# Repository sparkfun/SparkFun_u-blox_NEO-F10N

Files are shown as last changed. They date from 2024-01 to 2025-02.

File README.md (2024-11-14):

SparkFun GNSS L1/L5 Breakout- NEO-F10N, SMA
========================================

SparkFun GNSS L1/L5 Breakout - NEO-F10N, SMA (https://www.sparkfun.com/products/24114)

[*SparkFun GNSS L1/L5 Breakout - NEO-F10N, SMA (GPS-24114)*](https://www.sparkfun.com/products/24114)

The SparkFun GNSS L1/L5 Breakout - NEO-F10N, SMA is a standard precision GNSS board with meter-level positional accuracy. The NEO-F10N uses the L1/L5 bands instead of the more commonly seen L1/L2 bands. Utilizing the L5 band, the NEO-F10N delivers improved performance under challenging urban environments. The L5 signals fall within the protected ARNS (aeronautical radio navigation service) frequency band, leading to less RF interference.

This breakout supports the concurrent reception of three GNSS constellations: GPS, Galileo, and BeiDou. The proprietary dual-band multipath mitigation technology from the u-blox F10 allows the module to choose the best signals from both bands to achieve a significantly better position accuracy in challenging urban environments than with the L1 band alone.

What's different from other u-blox modules is that the NEO-F10N module only supports one serial UART communication port. We included a CH340 USB-to-serial converter to connect the board to a computer's USB port easily. For users connecting the board's serial UART pins to a microcontroller or radio, you will need to cut the USB-TX and USB-RX jumpers to avoid bus contention. Pins for power, serial, pulse per second, and control pins are broken out to 0.1"-spaced pins on the board's edge. We have also conveniently included a 1x6 header should you connect a BlueSMiRF v2 to transmit data wirelessly!

The breakout is also has an on-board rechargeable battery that provides power to the RTC on the NEO-F10N. This reduces the time-to-first fix from a cold start (~28s) to a hot start (2s). The battery will maintain RTC and GNSS orbit data without being connected to power for plenty of time. We have included an SMA connector for a secure connection.

U-blox-based GPS products are configurable using the popular but dense Windows program u-center. Plenty of different functions can be configured on the NEO-F10N: baud rates, update rates, spoofing detection, external interrupts, SBAS, etc. To get started, we've included a few basic UART examples with our SparkFun Arduino Library.

Repository Contents
-------------------
* **.github/workflows** - YAML files used for GitHub Actions and GitHub Pages/mkdocs
* **/Hardware** - KiCad design files (.brd, .sch)
  * **/Production** - Production panel files (.brd)
* **/docs** - Online documentation files
  * **/assets** - Folder containing all the file assets used for product documentation
    * **/3d_model** - Exported 3D models from KiCad
    * **/board_files** - Copy of design files used for product documentation
    * **/component_documentation** - Datasheets and manuals for hardware components
    * **/img** - Images for product documentation
  * **/github** - Files stating how to contribute and filing issues used for product documentation
  * **/javascript** - Folder containing custom javascript used for product documentation
  * **/stylesheet** - Folder containing CSS files used for product documentation
* **/overrides** - Customization files used for product documentation
  * **/.icons** - Icons used for GitHub used for product documentation
  * **./partials** - Used for product documentation

Documentation
--------------
* **[Library](https://github.com/sparkfun/SparkFun_u-blox_GNSS_v3)** - Arduino library for u-blox modules.
* **[Hookup Guide](https://docs.sparkfun.com/SparkFun_u-blox_NEO-F10N)** - Basic hookup guide for the NEO-F10N breakout board.

Product Versions
----------------
* [GPS-24114](https://www.sparkfun.com/products/24114) - Initial release

Version History
---------------
* v1.0 - Initial release

License Information
-------------------

This product is _**open source**_!

Please review the LICENSE.md file for license information.

If you have any questions or concerns on licensing, please contact technical support on our [SparkFun forums](https://forum.sparkfun.com/viewforum.php?f=152).

Distributed as-is; no warranty is given.

- Your friends at SparkFun.

_<COLLABORATION CREDIT>_

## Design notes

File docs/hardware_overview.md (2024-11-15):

In this section, we will highlight the hardware and pins that are broken out on the SparkFun GNSS L1/L5 Breakout - NEO-F10N, SMA. For more information, check out our [Resources and Going Further](../resources/) for the NEO-F10N.

<div style="text-align: center;">
  <table>
    <tr style="vertical-align:middle;">
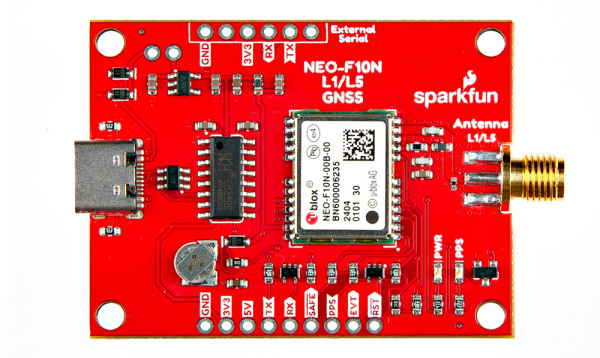
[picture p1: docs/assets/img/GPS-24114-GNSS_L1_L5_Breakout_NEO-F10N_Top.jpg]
     <td style="text-align: center; vertical-align: middle; border: solid 1px #cccccc;></td>
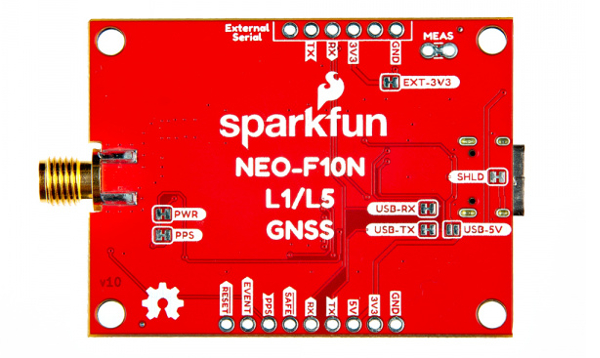
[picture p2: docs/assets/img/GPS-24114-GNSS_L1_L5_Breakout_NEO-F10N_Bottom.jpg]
Bottom View
     <td style="text-align: center; vertical-align: middle; border: solid 1px #cccccc;></td>
    </tr>
    <tr style="vertical-align:middle;">
     <td style="text-align: center; vertical-align: middle; border: solid 1px #cccccc;"><i>Top View</i></td>
     <td style="text-align: center; vertical-align: middle; border: solid 1px #cccccc;"><i>Bottom View</i></td>
    </tr>
  </table>
</div>

### NEO-F10N Module

The board breaks out the NEO-F10N with some application circuits.

<div style="text-align: center;">
  <table>
    <tr style="vertical-align:middle;">
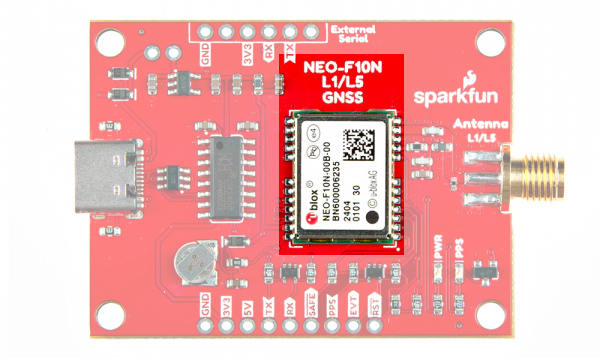
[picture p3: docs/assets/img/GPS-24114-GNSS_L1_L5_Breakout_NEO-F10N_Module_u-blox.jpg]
u-blox NEO-F10N Module
     <td style="text-align: center; vertical-align: middle; border: solid 1px #cccccc;></td>
    </tr>
    <tr style="vertical-align:middle;">
     <td style="text-align: center; vertical-align: middle; border: solid 1px #cccccc;"><i>u-blox NEO-F10N Module</i></td>
    </tr>
  </table>
</div>

Similar to the other u-blox engines, the NEO-F10N is a GNSS Receiver. The module supports the concurrent reception of three GNSS systems: GPS, Galileo, and BeiDou. The NEO-F10N utilizes the L1/L5 bands as opposed to other u-blox modules that use L1/L2, such as the [NEO-M9N](https://www.sparkfun.com/products/17285).

<div style="text-align: center;">
  <table>
    <tr style="vertical-align:middle;">
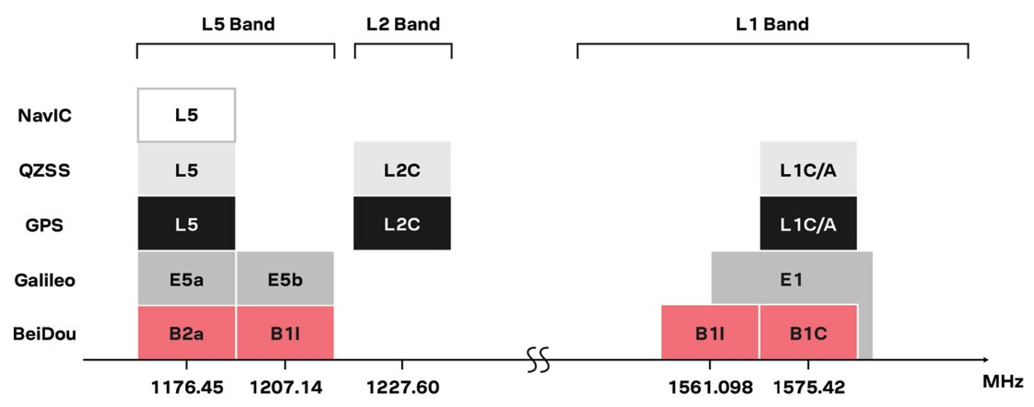
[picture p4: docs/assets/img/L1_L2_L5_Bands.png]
L1, L2, L5 GNSS Frequency Bands
     <td style="text-align: center; vertical-align: middle; border: solid 1px #cccccc;></td>
    </tr>
    <tr style="vertical-align:middle;">
     <td style="text-align: center; vertical-align: middle; border: solid 1px #cccccc;"">Image Courtesy of <a href="../assets/component_documentation/GPS-signals-migration-wp.pdf">u-blox: GPS Signals Migration White Paper</a></td>
    </tr>
  </table>
</div>

Utilizing the L5 band, the NEO-F10N delivers improved performance under challenging urban environments because the L5 signals fall within the protected ARNS (aeronautical radio navigation service) frequency band. This band is less subject to RF interference. Below is a comparison of a single-band (L1) vs dual-band (L1/L5) GNSS test with a car driving through an urban environment. Tracking the vehicle was better when utilizing the L1/L5 bands.

<div style="text-align: center;">
  <table>
    <tr style="vertical-align:middle;">
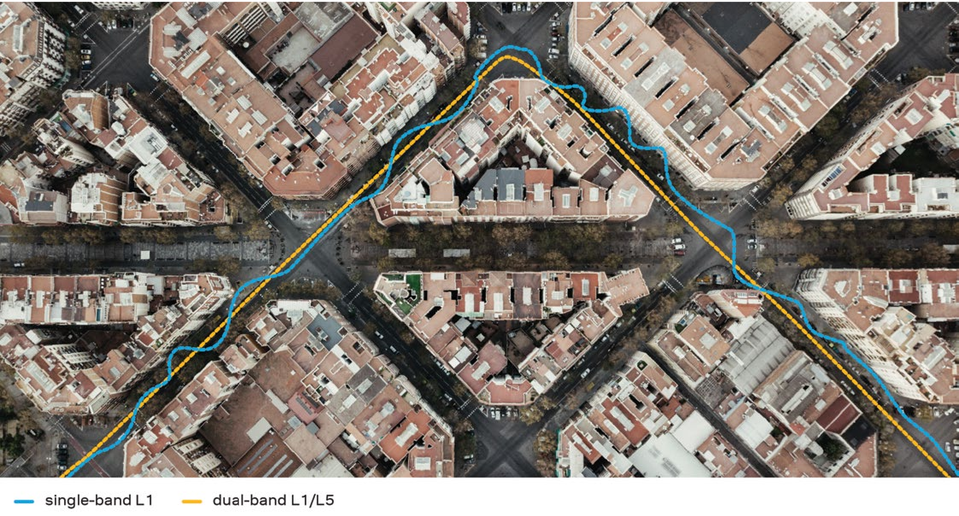
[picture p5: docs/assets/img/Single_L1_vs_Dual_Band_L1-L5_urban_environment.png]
     <td style="text-align: center; vertical-align: middle; border: solid 1px #cccccc;></td>
    </tr>
    <tr style="vertical-align:middle;">
     <td style="text-align: center; vertical-align: middle; border: solid 1px #cccccc;"><i>Image Courtesy of <a href="../assets/component_documentation/GPS-signals-migration-wp.pdf">u-blox: GPS Signals Migration White Paper</a></i></td>
    </tr>
  </table>
</div>

!!! note
    As of the writing of this tutorial, it is important to note that L5 band is still not yet fully operational on GPS and Galileo. It is expected to be fully operational by 2025.

The module can achieve meter-level accuracy with a satellite lock. Below are a few specs taken from the datasheet. For more information, check out the related [documents for the NEO-F10N in the Resources](../resources/).

* Time to First Fix: 28s (cold), 2s (hot)
* Max Navigation Rate for Single GNSS Configuration (GPS): 20 Hz
* Positional Accuracy (GPS): 1.5m
* Time Pulse Accuracy: 30ns
* Operational Limits
    * Max G: &le; 4G
    * Max Altitude: 80km (49.7 miles)
    * Max Velocity: 500m/s (1118mph)
* Software Configurable
    * Baud Rate (**38400 Baud**, default)
    * Odometer
    * Spoof Detection
    * External Interrupt
    * Pin Control
    * Many others!
* Supports: NMEA, UBX over UART

### Power

There are a variety of power and power-related nets broken out on the USB connector and through hole pads. **5V** power from the USB C Connector or PTH is regulated down to **3.3V** with the AP2112K 3.3V/600mA voltage regulator. The logic levels for the NEO-F10N is **3.3V** for the I/O pins.

* **5V** &mdash; Power from the USB C connector's VBUS provides power to the 5V bus. The 5V net is also connected to the edge PTH pin labeled as **5V** and the input of the 3.3V voltage regulator. Built-in Schottky diodes are included on the VBUS and 5V nets for protection. Make sure that power you provide to this pin does not exceed 6 volts.
* **3V3** &mdash; This connects to the 3.3V net. Both sides of the board includes a 3.3V pin (labeled as 3V3) that should only be provided with a clean 3.3V power signal.
* **GND** &mdash; Of course, is the common, ground voltage (0V reference) for the system.

<div style="text-align: center;">
  <table>
    <tr style="vertical-align:middle;">
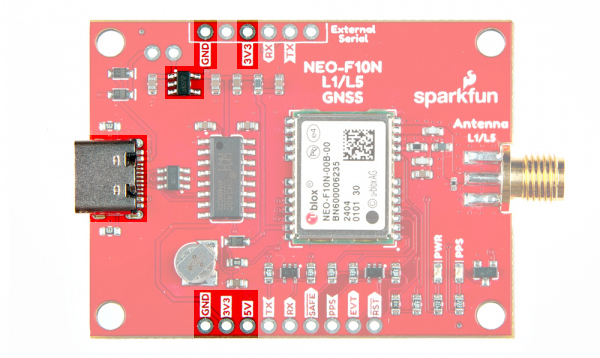
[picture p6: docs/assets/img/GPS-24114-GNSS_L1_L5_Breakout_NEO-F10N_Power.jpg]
Power Nets Highlighted
     <td style="text-align: center; vertical-align: middle; border: solid 1px #cccccc;"></td>
    </tr>
    <tr style="vertical-align:middle;">
     <td style="text-align: center; vertical-align: middle; border: solid 1px #cccccc;"><i>Power from USB and PTHs</i></td>
    </tr>
  </table>
</div>

### Backup Battery

The small metal disk is a small lithium battery. This battery does not provide power to the IC like the 3.3V system does, but to relevant systems inside the IC that allow for a quick reconnection to satellites. The first time to fix (TTFF) is about **~28 seconds**. With the backup battery, the hot start is less than **2 seconds**.

<div style="text-align: center;">
  <table>
    <tr style="vertical-align:middle;">
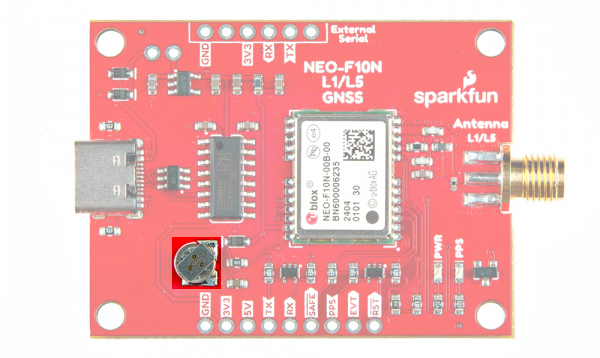
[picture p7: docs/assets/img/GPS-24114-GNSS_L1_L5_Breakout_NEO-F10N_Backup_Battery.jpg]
Backup Battery Highlighted
     <td style="text-align: center; vertical-align: middle; border: solid 1px #cccccc;"></td>
    </tr>
    <tr style="vertical-align:middle;">
     <td style="text-align: center; vertical-align: middle; border: solid 1px #cccccc;"><i>Backup Battery Highlighted</i></td>
    </tr>
  </table>
</div>

### CH340C USB-to-Serial Converter

The board includes a built-in CH340 USB-to-serial converter to connect the board to a computer's USB port. This is useful for users viewing data, configuring the NEO-F10N, or updating firmware through u-center graphical user interface (GUI). Of course, users can also view the serial data through a serial terminal as well.

<div style="text-align: center;">
  <table>
    <tr style="vertical-align:middle;">
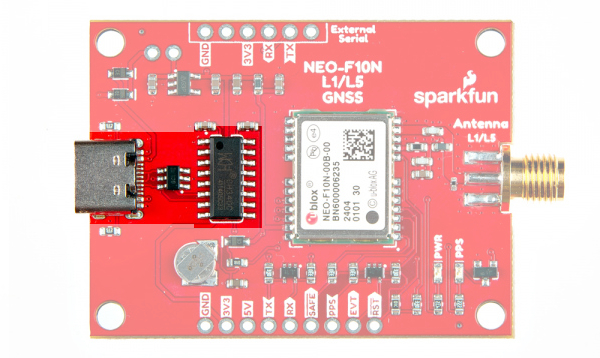
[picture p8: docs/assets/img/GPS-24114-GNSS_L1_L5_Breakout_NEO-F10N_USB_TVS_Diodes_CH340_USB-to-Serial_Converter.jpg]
CH340C Highlighted
     <td style="text-align: center; vertical-align: middle; border: solid 1px #cccccc;"></td>
    </tr>
    <tr style="vertical-align:middle;">
     <td style="text-align: center; vertical-align: middle; border: solid 1px #cccccc;"><i>USB, TVS Diodes, and CH340 Highlighted</i></td>
    </tr>
  </table>
</div>

### UART1

There are two pins on each row of headers currently labeled as **TX** and **RX** for the UART. Compared to other u-blox modules, there is no USB, I<sup>2</sup>C, SPI, or secondary UART port. The NEO-F10N has only one serial UART port available. The default baud rate is set to **38400 baud**, 8-bits, no parity, and 1 stop bit. The NEO-F10N is set to output the following messages by default: NMEA GGA, GLL, GSA, GSV, RMC, VTG and TXT.

* **TX** &mdash; TX out from the NEO-F10N
* **RX** &mdash; RX into the NEO-F10N

<div style="text-align: center;">
  <table>
    <tr style="vertical-align:middle;">
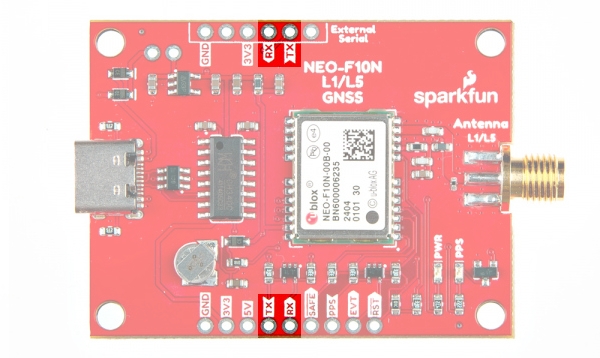
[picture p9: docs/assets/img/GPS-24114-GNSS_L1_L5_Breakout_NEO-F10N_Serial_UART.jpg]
UART1 Highlighted
     <td style="text-align: center; vertical-align: middle; border: solid 1px #cccccc;"></td>
    </tr>
    <tr style="vertical-align:middle;">
     <td style="text-align: center; vertical-align: middle; border: solid 1px #cccccc;"><i>UART Pins Highlighted</i></td>
    </tr>
  </table>
</div>

These pins are currently tied to the CH340's UART pins. For users connecting the board's serial UART pins to a microcontroller or radio, you will need to cut the USB-TX and USB-RX jumpers to avoid [bus contention](https://learn.sparkfun.com/tutorials/serial-communication/common-pitfalls).  

The 1x6 header labeled as "External Serial" can be used to connect to any other serial device that has a standard serial UART header. For example, you can connect a BlueSMiRF v2 wirelessly stream serial data using SPP to a smartphone's Bluetooth&reg; or a second BlueSMiRF.

<div style="text-align: center;">
  <table>
    <tr style="vertical-align:middle;">
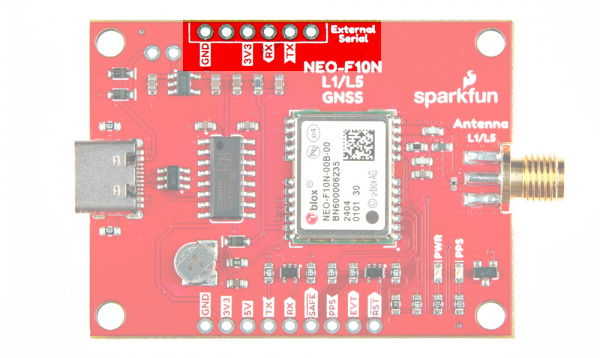
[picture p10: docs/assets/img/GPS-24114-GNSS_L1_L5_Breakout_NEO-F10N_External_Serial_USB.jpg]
External Serial Highlighted
     <td style="text-align: center; vertical-align: middle; border: solid 1px #cccccc;"></td>
    </tr>
    <tr style="vertical-align:middle;">
     <td style="text-align: center; vertical-align: middle; border: solid 1px #cccccc;"><i>External Serial Highlighted</i></td>
    </tr>
  </table>
</div>

### SMA Connector

The board is populated with one SMA connector for a secure connection. You will need a multiband GNSS antenna capable of receiving L1 and L5 bands to get the most out of the NEO-F10N. Note that this is intended for active antennas. We recommend using the
[GNSS L1/L5 Multi-Band High Precision Antenna - 5m (SMA)](https://www.sparkfun.com/products/23814). You will also need an [antenna ground plate](https://www.sparkfun.com/products/17519)

<div style="text-align: center;">
  <table>
    <tr style="vertical-align:middle;">
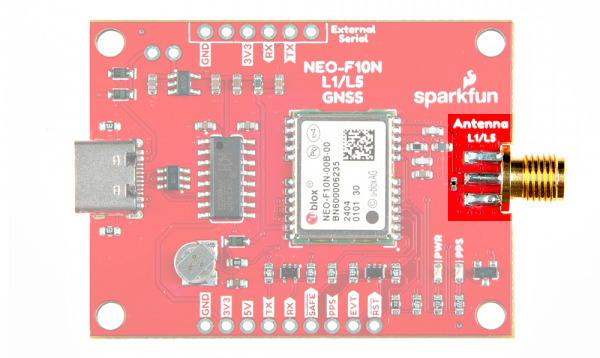
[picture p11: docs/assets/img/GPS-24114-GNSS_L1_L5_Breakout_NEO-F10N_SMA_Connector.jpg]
SMA Connector Highlighted
     <td style="text-align: center; vertical-align: middle; border: solid 1px #cccccc;"></td>
    </tr>
    <tr style="vertical-align:middle;">
     <td style="text-align: center; vertical-align: middle; border: solid 1px #cccccc;"><i>SMA Connector Highlighted</i></td>
    </tr>
  </table>
</div>

### Broken Out Pins

There are four other pins broken out:

* **<span STYLE="text-decoration:overline">SAFE</span>** &mdash; Safeboot input pin. This is required for firmware updates to the module and generally should not be used or connected.
* **PPS** &mdash; Pulse-per-second output pin. Begins blinking at 1Hz when module gets basic GPS/GNSS position lock.
* **EVENT** &mdash; Interrupt input/output pin. Can be configured using U-Center to bring the module out of deep sleep or to output an interrupt for various module states.
* **<span STYLE="text-decoration:overline">RST</span>**/ **<span STYLE="text-decoration:overline">RESET</span>** &mdash; Reset input pin. Pull this line low to reset the module.

<div style="text-align: center;">
  <table>
    <tr style="vertical-align:middle;">
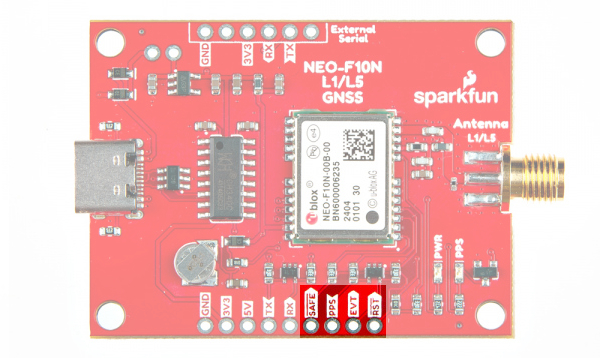
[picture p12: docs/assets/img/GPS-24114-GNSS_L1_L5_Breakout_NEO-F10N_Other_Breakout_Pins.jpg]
     <td style="text-align: center; vertical-align: middle; border: solid 1px #cccccc;"></td>
    </tr>
    <tr style="vertical-align:middle;">
     <td style="text-align: center; vertical-align: middle; border: solid 1px #cccccc;"><i>Other Breakout Pins Highlighted</i></td>
    </tr>
  </table>
</div>

### LEDs

The board includes the following status LEDs as indicated in the image below.

* **PWR** &mdash; Indicates when the NEO-F10N is powered.
* **PPS** &mdash; Tied to the Pulse Per Second pin and acts as a visual indicator to the NEO-F10N's pulse per second signal.

<div style="text-align: center;">
  <table>
    <tr style="vertical-align:middle;">
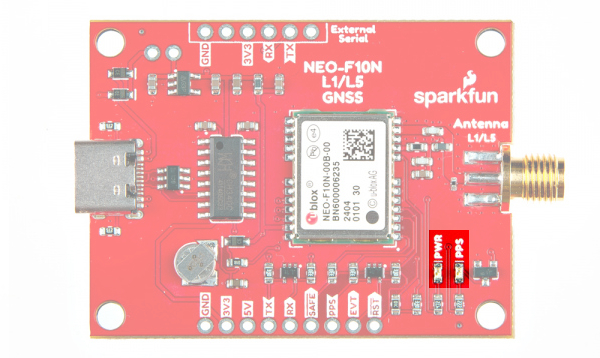
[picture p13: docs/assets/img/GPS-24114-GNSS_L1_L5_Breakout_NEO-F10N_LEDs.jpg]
LEDs Highlighted
     <td style="text-align: center; vertical-align: middle; border: solid 1px #cccccc;"></td>
    </tr>
    <tr style="vertical-align:middle;">
     <td style="text-align: center; vertical-align: middle; border: solid 1px #cccccc;"><i>LEDs Highlighted</i></td>
    </tr>
  </table>
</div>

### Jumpers

!!!note
    If this is your first time working with jumpers, check out the [How to Work with Jumper Pads and PCB Traces](https://learn.sparkfun.com/tutorials/how-to-work-with-jumper-pads-and-pcb-traces/all) tutorial for more information.

If you flip the board over, you will notice a few jumper pads.

* **SHLD** &mdash; This jumper connects the USB Type C connector's shield pin to GND. By default, this is closed. Cut this to isolate the USB Type C connector's shield pin.
* **USB-5V** &mdash; This jumper connects the 5V net to the 5V VBUS net. By default, this is open. Add a solder blob to the jumper to connect 5V PTH to the USB's VBUS.
* **MEAS** &mdash; By default, the jumper is closed. You can cut this jumper and solder to the PTHs to measure the NEO-F10N's current draw from either the USB's VBUS or 5V net. Just make sure to close the jumper if you decide to still use power from the USB or the 5V pin.
* **USB-TX** &mdash; The USB-TX jumper connects the CH340 USB-to-Serial converter's RX pin to the  NEO-F10N's TX pin. As stated earlier, cut this trace when connecting another serial device on the PTH to avoid bus contention.
* **USB-RX** &mdash; The USB-RX jumper connects the CH340 USB-to-Serial converter's TX pin to the  NEO-F10N's RX pin. As stated earlier, cut this trace when connecting another serial device on the PTH to avoid bus contention.
* **EXT-3V3** &mdash; This jumper connects 3.3V to the external serial port. By default, this is closed and will provide power to anything connected to the external serial port. To avoid conflicting voltages, cut this jumper if you are connecting 3.3V USB device with its own power source to the 1x6 header while the GNSS receiver is being powered with its own power source.
* **PWR** &mdash; The power LED will illuminate when 3.3V is activated either over USB or via the 3v3 pin. Cut this jumper to disable the LED.
* **PPS** &mdash; The pulse per second LED will illuminate each second once a position lock has been achieved. Cut this jumper to disable the LED.

<div style="text-align: center;">
  <table>
    <tr style="vertical-align:middle;">
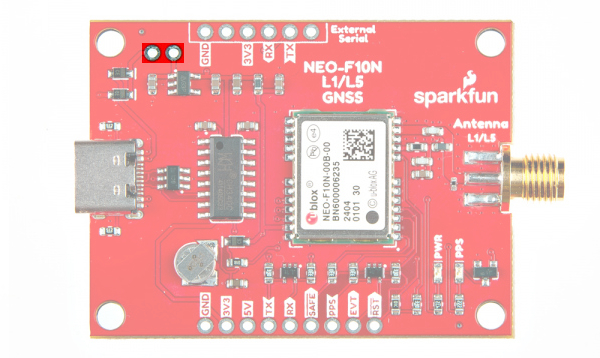
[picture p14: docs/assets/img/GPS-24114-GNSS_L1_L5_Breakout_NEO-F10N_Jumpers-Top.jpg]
Jumpers Highlighted
     <td style="text-align: center; vertical-align: middle; border: solid 1px #cccccc;"></td>
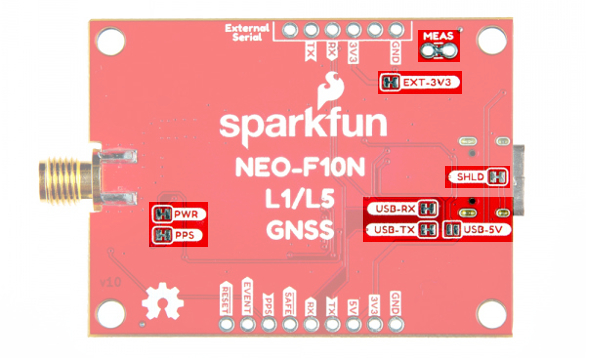
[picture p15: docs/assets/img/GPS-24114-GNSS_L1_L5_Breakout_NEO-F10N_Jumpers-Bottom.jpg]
Jumpers Highlighted
     <td style="text-align: center; vertical-align: middle; border: solid 1px #cccccc;"></td>
    </tr>
    <tr style="vertical-align:middle;">
     <td style="text-align: center; vertical-align: middle; border: solid 1px #cccccc;"><i>MEAS PTH Highlighted - Top View</i></td>
     <td style="text-align: center; vertical-align: middle; border: solid 1px #cccccc;"><i>Jumpers Highlighted Highlighted - Bottom View</i></td>
    </tr>
  </table>
</div>

### 3D Model

3D models of the board and components were exported to STEP and STL files using KiCad.

<!-- Import the component -->
<script type="module" src="https://ajax.googleapis.com/ajax/libs/model-viewer/3.5.0/model-viewer.min.js"></script>

<div style="text-align: center;">
    <model-viewer src="../assets/3d_model/SparkFun_NEO-F10N_3D_model.glb" camera-controls poster="../assets/3d_model/SparkFun_NEO-F10N_3D_image.png" environment-image="legacy" shadow-intensity="1.58" exposure="0.64" shadow-softness="0.24" tone-mapping="neutral" camera-orbit="-46.67deg 57.14deg 153.3m" field-of-view="30deg" style="width: 750px; height: 500px;">
    </model-viewer>
</div>
<br />
<div style="text-align: center">
    <a href="../assets/3d_model/SparkFun_NEO-F10N_3D_model.step" target="stp_file" class="md-button">Click Here for the STEP File</a>
</div>

### Board Dimensions

The board is 50.8mm x 38.1mm (2.0" x 1.5). This is not including the SMA connector. There are 4x mounting holes by each corner of the board for 4-40 screws and standoffs.

<div style="text-align: center;">
  <table>
    <tr style="vertical-align:middle;">
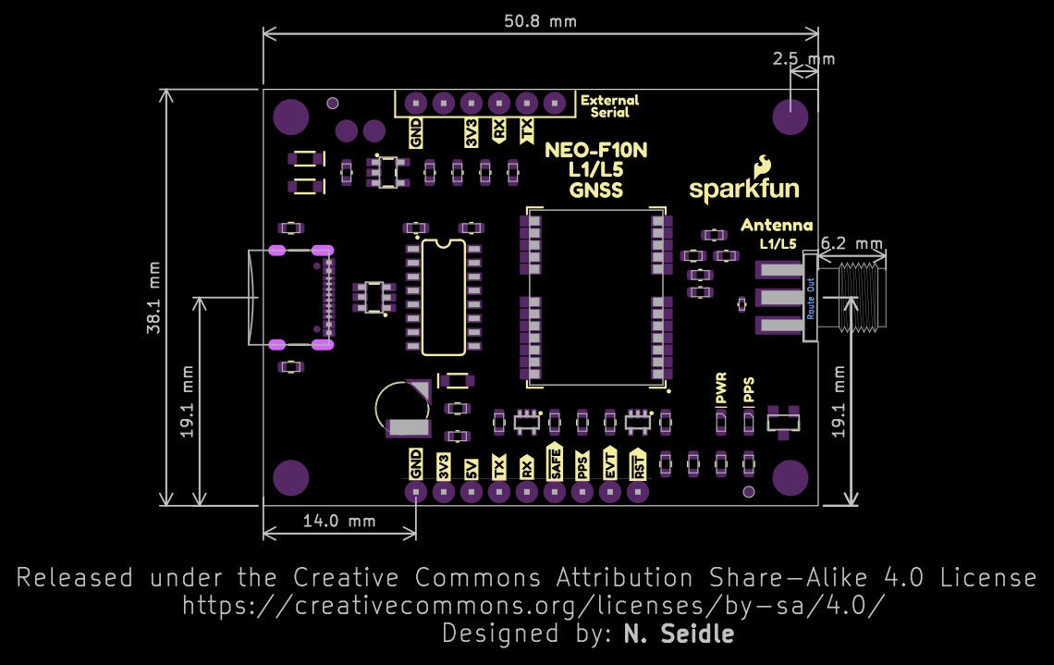
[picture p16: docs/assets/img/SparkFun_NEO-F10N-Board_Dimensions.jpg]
Board Dimensions
     <td style="text-align: center; vertical-align: middle; border: solid 1px #cccccc;"></td>
    </tr>
    <tr style="vertical-align:middle;">
     <td style="text-align: center; vertical-align: middle; border: solid 1px #cccccc;"><i>Board Dimensions</i></td>
    </tr>
  </table>
</div>

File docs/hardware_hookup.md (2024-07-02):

In this section, we'll go over how to connect the L1/L5 GNSS Antenna to the SparkFun GNSS L1/L5 Breakout - NEO-F10N. Depending on your application, you can connect the SparkFun GNSS L1/L5 Breakout - NEO-F10N directly to your computer.  For embedded application, you will want to connect the SparkFun GNSS L1/L5 Breakout - NEO-F10N to the IoT RedBoard - ESP32.

### L1/L5 Dual-Band GNSS Antenna

Connect a compatible dual-band antenna that is capable of receiving L1 and L5 bands. In this case, we used the "GNSS L1/L5 Multi-Band High Precision Antenna - 5m (SMA)." Insert the SMA side of the interface cable into the GNSS L1/L5 Breakout Board's SMA connector. Secure the connection by using the SMA's hex nut until it is finger-tight.

<div style="text-align: center;">
  <table>
    <tr style="vertical-align:middle;">
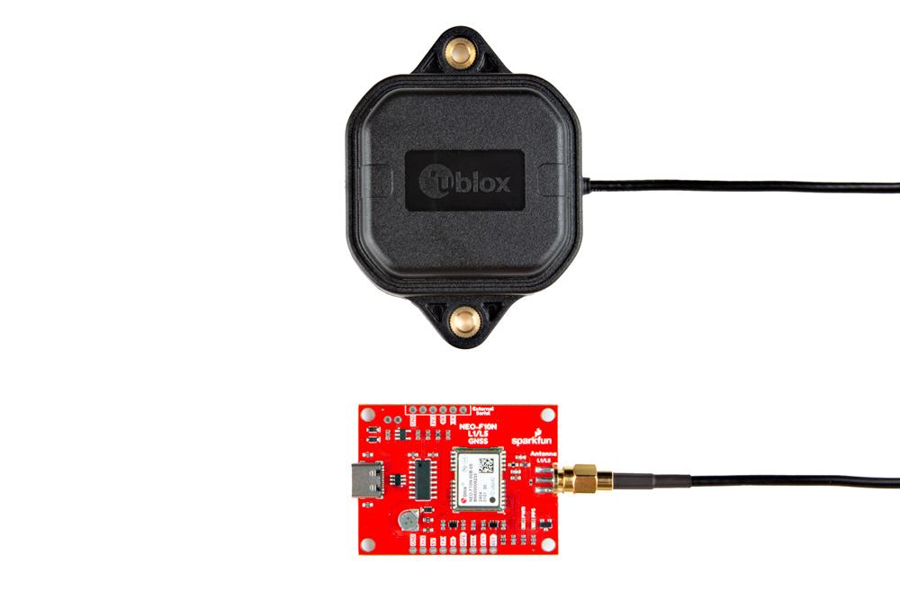
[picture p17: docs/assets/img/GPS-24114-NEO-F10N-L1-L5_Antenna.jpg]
Antenna Connected to Breakout Board
     <td style="text-align: center; vertical-align: middle;"></td>
    </tr>
  </table>
</div>

You will need to include an [antenna ground plate](https://www.sparkfun.com/products/17519) to get the most of the multi-band antenna. For the following images below, we'll have the magnetic mount antenna separate from the antenna ground plate when connecting the NEO-F10N breakout board to the rest of the system. When running the examples, make sure to have the antenna mounted over a metal ground plate.

<div style="text-align: center;">
  <table>
    <tr style="vertical-align:middle;">
     <td style="text-align: center; vertical-align: middle;"><a href="https://cdn.sparkfun.com//assets/parts/1/6/5/9/3/17519-GPS_Antenna_Ground_Plate-05.jpg">GNSS Antenna Magnetically Mounted on Metal Antenna Ground Plate</a></td>
    </tr>
  </table>
</div>

!!! note
    Not all multiband antennas are made the same! Make sure that you are connecting a multi-band antenna that is capable of receiving L1/L5 signals when using the SparkFun GNSS L1/L5 Breakout - NEO-F10N. There is also another u-blox antenna that looks the same. However, the u-blox antenna used in this tutorial receives L1/L5 signals as opposed to the L1/L2.

### USB to NEO-F10N

For users that simply want to connect to the board via USB, you will just need to insert a USB C cable into the USB connector. Then connect the other end to your computer's USB port.

<div style="text-align: center;">
  <table>
    <tr style="vertical-align:middle;">
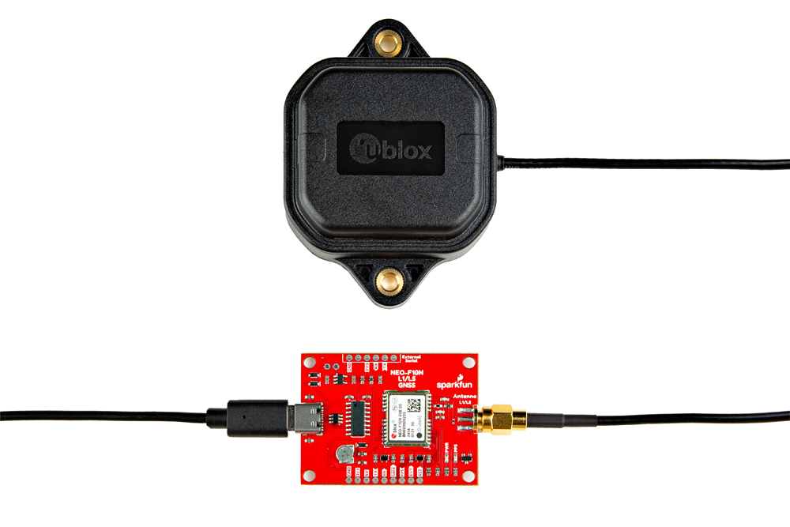
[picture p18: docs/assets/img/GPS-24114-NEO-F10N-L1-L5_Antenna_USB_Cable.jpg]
USB Cable Inserted into NEO-F10N
     <td style="text-align: center; vertical-align: middle;"></td>
    </tr>
  </table>
</div>

### Connecting via UART Port

!!! note
    We recommend using the IoT RedBoard - ESP32 for the scope of this tutorial.

For users that are connecting to a microcontroller, you will need to adjust the jumpers and solder to the PTH before connecting to the SparkFun GNSS L1/L5 Breakout - NEO-F10N.

#### Cutting the Serial Jumpers

For this example, we will connect the NEO-F10N to the IoT RedBoard - ESP32. Remember, the NEO-F10N has only one UART. You will need to cut the two jumpers on the back of the board labeled as USB-RX and USB-TX so that there is no [bus contention](https://learn.sparkfun.com/tutorials/serial-communication/common-pitfalls).

<div style="text-align: center;">
  <table>
    <tr style="vertical-align:middle;">
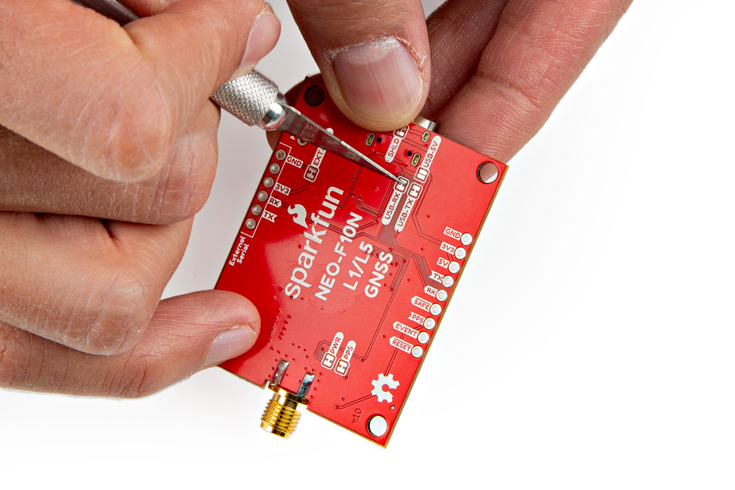
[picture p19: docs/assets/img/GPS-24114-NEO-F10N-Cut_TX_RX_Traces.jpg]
Cut Jumpers
     <td style="text-align: center; vertical-align: middle;"></td>
    </tr>
  </table>
</div>

#### Connecting via PTH

Once the jumpers have been cut, you will need to solder to the through hole pins. For temporary connections to the PTHs, you could use IC hooks to test out the pins. However, you'll need to solder headers or wires of your choice to the board for a secure connection. You can choose between a combination of [header pins and jumper wires](https://learn.sparkfun.com/tutorials/how-to-solder-through-hole-soldering/all), or [stripping wire and soldering the wire](https://learn.sparkfun.com/tutorials/working-with-wire/all) directly to the board.

<div class="grid cards col-4" markdown>

-   <a href="https://learn.sparkfun.com/tutorials/how-to-solder-through-hole-soldering/all">
      <figure markdown>
        How to Solder: Through Hole Soldering
      </figure>
    </a>

    ---

    <a href="https://learn.sparkfun.com/tutorials/how-to-solder-through-hole-soldering/all">
      <b>How to Solder: Through Hole Soldering</b>
    </a>
<!-- ----------WHITE SPACE BETWEEN GRID CARDS---------- -->

-   <a href="https://learn.sparkfun.com/tutorials/working-with-wire/all">
      <figure markdown>
        Working with Wire
      </figure>
    </a>

    ---

    <a href="https://learn.sparkfun.com/tutorials/working-with-wire/all">
      <b>Working with Wire</b>
    </a>
<!-- ----------WHITE SPACE BETWEEN GRID CARDS---------- -->
</div>

We decided to solder straight header pins to the 1x6 External Serial port. Your setup will look similar to the image below.

<div style="text-align: center;">
  <table>
    <tr style="vertical-align:middle;">
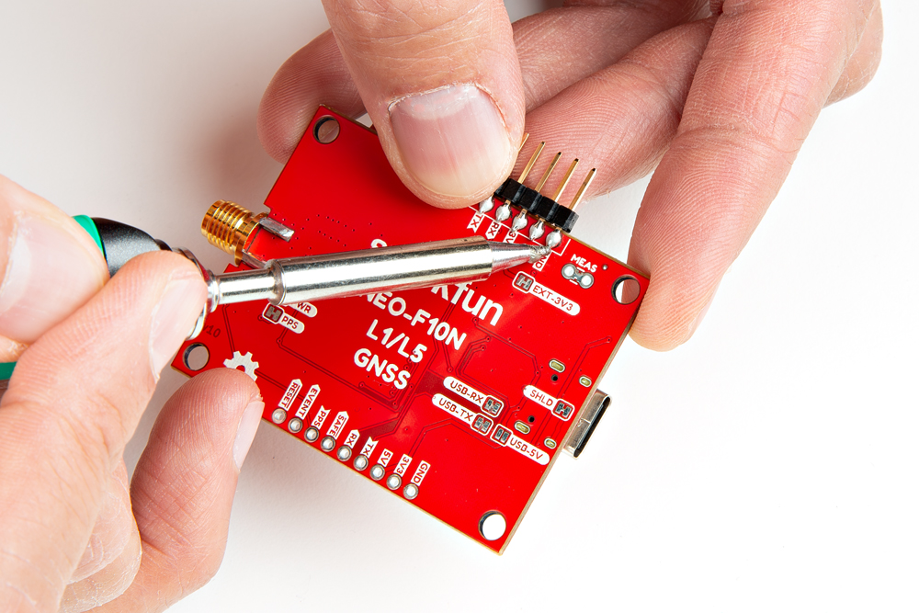
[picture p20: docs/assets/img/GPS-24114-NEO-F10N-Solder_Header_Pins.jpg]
Straight Header Pins connected to 1x6 Serial Port
     <td style="text-align: center; vertical-align: middle;"></td>
    </tr>
  </table>
</div>

You will then need to connect power and the UART pins between the boards. Below is an example of connecting the IoT RedBoard - ESP32's second hardware UART port. When initializing the serial, make sure to define your microcontroller's hardware serial, such as `Serial1` or `Serial2`. In this case, we needed to use UART2 for the IoT RedBoard - ESP32.

<div style="text-align: center;">
    <table>
        <tr>
            <th style="text-align: center; border: solid 1px #cccccc;">IoT RedBoard - ESP32
            </th>
            <th style="text-align: center; border: solid 1px #cccccc;">SparkFun GNSS L1/L5 Breakout - NEO-F10N
            </th>
        </tr>
        <tr>
            <td style="text-align: center; border: solid 1px #cccccc;" bgcolor="#f2dede"><font color="#000000">3.3V</font>
            </td>
            <td style="text-align: center; border: solid 1px #cccccc;" bgcolor="#f2dede"><font color="#000000">3V3</font>
            </td>
        </tr>
        <tr>        
            <td style="text-align: center; border: solid 1px #cccccc;" bgcolor="#fff3cd"><font color="#000000">UART2_TX (D17)</font>
            </td>
            <td style="text-align: center; border: solid 1px #cccccc;" bgcolor="#fff3cd"><font color="#000000">RX</font>
            </td>
        </tr>
        <tr>        
            <td style="text-align: center; border: solid 1px #cccccc;" bgcolor="#cce5ff"><font color="#000000">UART2_RX (D16)</font>
            </td>
            <td style="text-align: center; border: solid 1px #cccccc;" bgcolor="#cce5ff"><font color="#000000">TX</font>
            </td>
        </tr>
        <tr>
            <td style="text-align: center; border: solid 1px #cccccc;" bgcolor="#d4edda"><font color="#000000">GND</font>
            </td>
            <td style="text-align: center; border: solid 1px #cccccc;" bgcolor="#d4edda"><font color="#000000">GND</font>
            </td>
        </tr>
    </table>
</div>

<div style="text-align: center;">
  <table>
    <tr style="vertical-align:middle;">
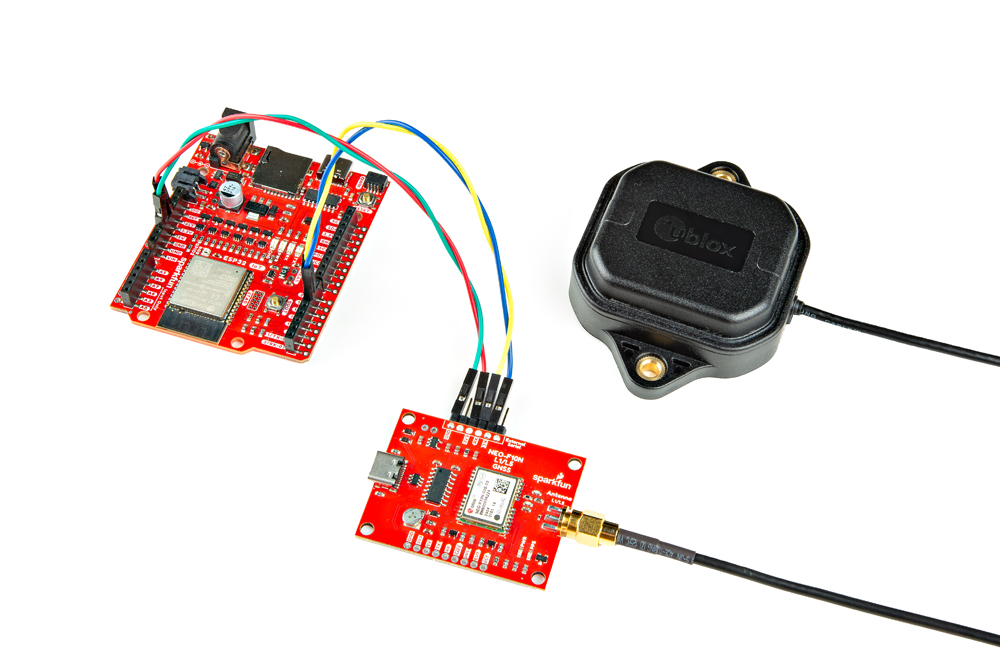
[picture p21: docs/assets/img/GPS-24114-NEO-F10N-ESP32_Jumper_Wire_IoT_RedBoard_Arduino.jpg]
NEO-F10N Breakout to Microcontroller with USB
     <td style="text-align: center; vertical-align: middle;"></td>
    </tr>
  </table>
</div>

!!! note
    Note that some microcontrollers may not have enough memory and will not be compatible with the SparkFun u-blox GNSS Arduino Library v3 (i.e. ATmega328P on the RedBoard Plus and the Arduino Uno). There are also some microcontrollers that only have one hardware UART so you need to make sure that there are only two serial devices on the bus.

#### USB to Microcontroller

To power and program the IoT RedBoard - ESP32, users will just need to insert the Type C side of the cable to the development board. The other end will connect to a computer's USB port.

<div style="text-align: center;">
  <table>
    <tr style="vertical-align:middle;">
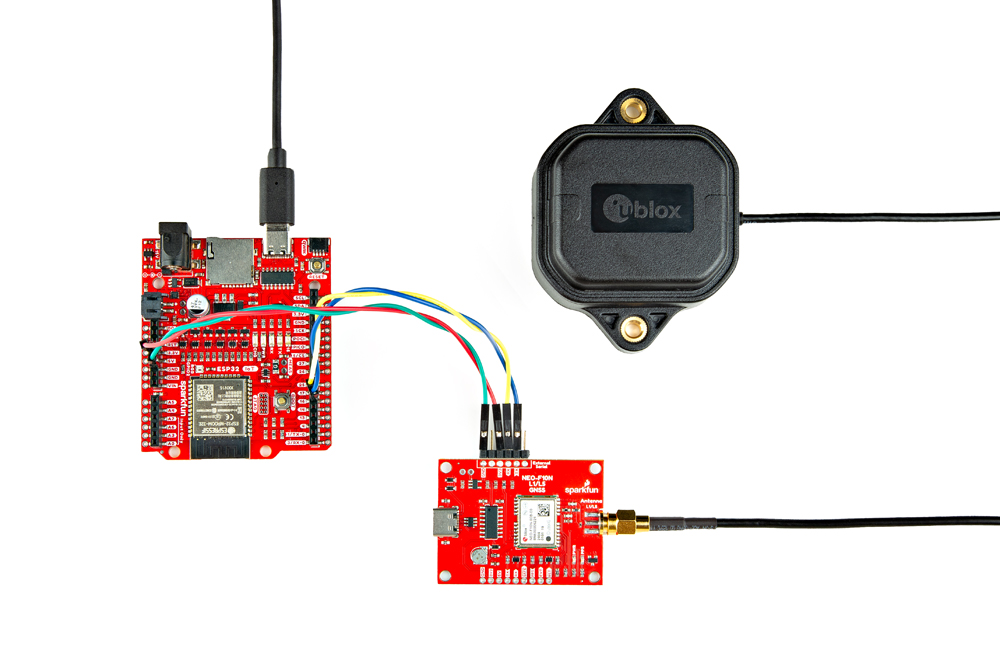
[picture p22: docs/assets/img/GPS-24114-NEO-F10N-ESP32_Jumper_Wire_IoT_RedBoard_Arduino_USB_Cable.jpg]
USB Cable Inserted into IoT RedBoard - ESP32 and NEO-F10N
     <td style="text-align: center; vertical-align: middle;"></td>
    </tr>
  </table>
</div>

#### Connecting a Pair of BlueSMiRF V2s

For users that want have a wireless connecting between the IoT RedBoard - ESP32 and the SparkFun GNSS L1/L5 Breakout Board - NEO-F10N, you could add a pair of BlueSMiRF V2s.

<div style="text-align: center;">
  <table>
    <tr style="vertical-align:middle;">
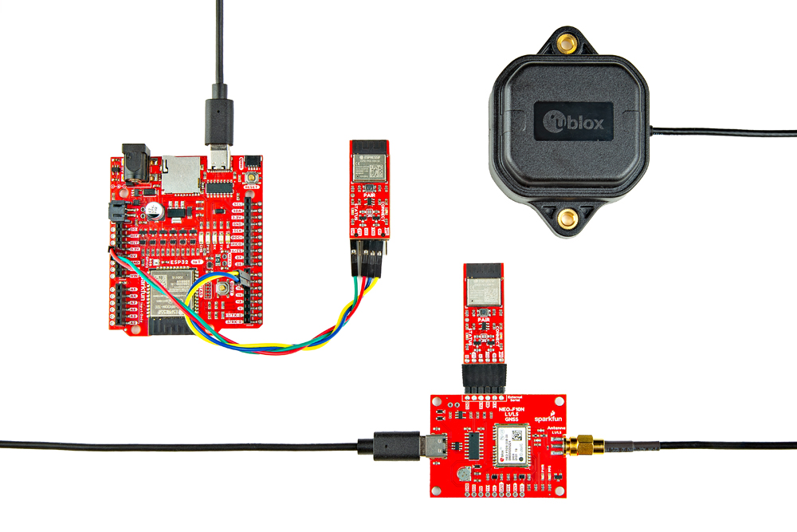
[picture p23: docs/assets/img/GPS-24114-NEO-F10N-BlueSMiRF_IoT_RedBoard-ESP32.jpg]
USB Cable Inserted into IoT RedBoard - ESP32/BlueSMiRF/Computer and USB Cable Inserted into BlueSMiRF/NEO-F10N
     <td style="text-align: center; vertical-align: middle;"></td>
    </tr>
  </table>
</div>

If you have not already, check out the [tutorial on the BlueSMiRFs](https://docs.sparkfun.com/SparkFun_BlueSMiRF-v2/introduction/) if you decide to wireless transmit the data.

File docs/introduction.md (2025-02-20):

The [SparkFun GNSS L1/L5 Breakout - NEO-F10N, SMA](https://www.sparkfun.com/products/24114) is a standard precision GNSS board with meter-level positional accuracy. The NEO-F10N uses the L1/L5 bands instead of the more commonly seen L1/L2 bands. Utilizing the L5 band, the NEO-F10N delivers improved performance under challenging urban environments the L5 signals fall within the protected ARNS (aeronautical radio navigation service) frequency band. This band is less subject to RF interference.

<center>
<div class="grid cards" style="width:500px;" markdown>

-   <a href="https://www.sparkfun.com/products/24114">
      <figure markdown>
        SparkFun GNSS L1/L5 Breakout - NEO-F10N, SMA
      </figure>
    </a>

    ---

    <a href="https://www.sparkfun.com/products/24114">
      <b>SparkFun GNSS L1/L5 Breakout - NEO-F10N, SMA</b>
      <br />
      GPS-24114
      <br />
      <center>[Purchase from SparkFun :fontawesome-solid-cart-plus:](https://www.sparkfun.com/products/24114){ .md-button .md-button--primary }</center>
    </a>
</div>
</center>

<div style="text-align: center;">
  <iframe width="560" height="315" src="https://www.youtube.com/embed/lrZWDXNU0OE?si=9YpjbiSuIA6uKVQY" title="YouTube video player" frameborder="0" allow="accelerometer; autoplay; clipboard-write; encrypted-media; gyroscope; picture-in-picture; web-share" referrerpolicy="strict-origin-when-cross-origin" allowfullscreen></iframe>
</div>

This breakout supports concurrent reception of three GNSS constellations: GPS, Galileo, and BeiDou. The proprietary dual-band [multipath mitigation technology](https://www.u-blox.com/en/technologies/multipath-mitigation) from the u-blox F10 allows the module to choose the best signals from both bands to achieve a significantly better position accuracy in challenging urban environments than with the L1 band alone.

What's different from other u-blox modules is that the NEO-F10N module only supports one serial UART communication port. U-blox based GPS products are configurable using the popular, but dense, windows program called u-center. Plenty of different functions can be configured on the NEO-F10N: baud rates, update rates, spoofing detection, external interrupts, SBAS, etc. We've included a few basic UART examples with our SparkFun Arduino Library to get started.

In this tutorial, we'll go over the hardware and how to hookup the breakout board. We will also go over a few basic Arduino examples to get started!

### Required Materials

To follow along with this tutorial, you will need the following materials at a minimum. You may not need everything though depending on what you have. Add it to your cart, read through the guide, and adjust the cart as necessary.

* 1x [SparkFun GNSS L1/L5 Breakout - NEO-F10N, SMA [GPS-24114]](https://www.sparkfun.com/products/24114)
* 1x [Reversible USB A to C Cable - 0.8m [CAB-15425]](https://www.sparkfun.com/products/15425)
* 1x [Reinforced Interface Cable - SMA Male to TNC Male (10m) [CAB-21740]](https://www.sparkfun.com/products/21740)
* 1x [GNSS L1/L5 Multi-Band High Precision Antenna - 5m (SMA) [GPS-23814]](https://www.sparkfun.com/products/23814)
* 1x [SparkFun IoT RedBoard - ESP32 Development Board [WRL-19177]](https://www.sparkfun.com/products/19177)

<div class="grid cards col-4" markdown>

<!-- ----------WHITE SPACE BETWEEN PRODUCTS---------- -->
-   <a href="https://www.sparkfun.com/products/24114">
      <figure markdown>
        SparkFun GNSS L1/L5 Breakout - NEO-F10N, SMA
      </figure>
    </a>

    ---

    <a href="https://www.sparkfun.com/products/2322411488">
      <b>SparkFun GNSS L1/L5 Breakout - NEO-F10N, SMA</b>
      <br />
      GPS-24114
    </a>
<!-- ----------WHITE SPACE BETWEEN PRODUCTS---------- -->
-   <a href="https://www.sparkfun.com/products/15425">
      <figure markdown>
        Reversible USB A to C Cable - 0.8m
      </figure>
    </a>

    ---

    <a href="https://www.sparkfun.com/products/15425">
      <b>Reversible USB A to C Cable - 0.8m</b>
      <br />
      CAB-15425
    </a>
<!-- ----------WHITE SPACE BETWEEN PRODUCTS---------- -->
-   <a href="https://www.sparkfun.com/products/17519">
      <figure markdown>
        GPS Antenna Ground Plate
      </figure>
    </a>

    ---

    <a href="https://www.sparkfun.com/products/17519">
      <b>GPS Antenna Ground Plate</b>
      <br>
      GPS-17519
    </a>
<!-- ----------WHITE SPACE BETWEEN PRODUCTS---------- -->
-   <a href="https://www.sparkfun.com/products/23814">
      <figure markdown>
        GNSS L1/L5 Multi-Band High Precision Antenna - 5m (SMA)
      </figure>
    </a>

    ---

    <a href="https://www.sparkfun.com/products/23814">
      <b>GNSS L1/L5 Multi-Band High Precision Antenna - 5m (SMA)</b>
      <br>
      GPS-23814
    </a>
<!-- ----------WHITE SPACE BETWEEN PRODUCTS---------- -->
-   <a href="https://www.sparkfun.com/products/19177">
      <figure markdown>
        SparkFun IoT RedBoard - ESP32 Development Board
      </figure>
    </a>

    ---

    <a href="https://www.sparkfun.com/products/19177">
      <b>SparkFun IoT RedBoard - ESP32 Development Board</b>
      <br />
      WRL-19177
    </a>
<!-- ----------WHITE SPACE BETWEEN PRODUCTS---------- -->
</div>

### GNSS Accessories

Depending on your setup, you may need the following mounting hardware. As included earlier in the required materials, the antenna ground plate below is needed when using multi-band antennas that do not have a good ground plane.

<!--
* 1x [GPS Antenna Ground Plate [GPS-17519]](https://www.sparkfun.com/products/17519)
* 1x [GNSS L1/L5 Multi-Band High Precision Antenna - 5m (SMA) [GPS-23814]](https://www.sparkfun.com/products/23814)

-->

<div class="grid cards col-4" markdown>
<!-- ----------WHITE SPACE BETWEEN PRODUCTS---------- -->
-   <a href="https://www.sparkfun.com/products/23814">
      <figure markdown>
        GNSS L1/L5 Multi-Band High Precision Antenna - 5m (SMA)
      </figure>
    </a>

    ---

    <a href="https://www.sparkfun.com/products/23814">
      <b>GNSS L1/L5 Multi-Band High Precision Antenna - 5m (SMA)</b>
      <br>
      GPS-23814
    </a>
<!-- ----------WHITE SPACE BETWEEN PRODUCTS---------- -->
-   <a href="https://www.sparkfun.com/products/17519">
      <figure markdown>
        GPS Antenna Ground Plate
      </figure>
    </a>

    ---

    <a href="https://www.sparkfun.com/products/17519">
      <b>GPS Antenna Ground Plate</b>
      <br>
      GPS-17519
    </a>
<!-- ----------WHITE SPACE BETWEEN PRODUCTS---------- -->
</div>

For users that decide to use the SPK6618H multi-band antenna as an alternative, users would not need to include the antenna ground plate. The mounting hardware listed below is also typically used with the SPK6618H multi-band antennas. The reinforced interface cable between the SMA to TNC also needed for the SPK6618H multi-band antennas.

<!--
* [GNSS Magnetic Mount [PRT-21257]](https://www.sparkfun.com/products/21257)
* [GNSS Antenna Mounting Hardware Kit [KIT-22197]](https://www.sparkfun.com/products/22197)
* [Reinforced Interface Cable - SMA Male to TNC Male (10m) [CAB-21740]](https://www.sparkfun.com/products/21740)
* [GNSS Multi-Band L1/L2/L5 Surveying Antenna - TNC (SPK6618H) [GPS-21801]](https://www.sparkfun.com/products/21801)

-->

<div class="grid cards col-4" markdown>

-   <a href="https://www.sparkfun.com/products/21801">
      <figure markdown>
        GNSS Multi-Band L1/L2/L5 Surveying Antenna - TNC (SPK6618H)
      </figure>
    </a>

    ---

    <a href="https://www.sparkfun.com/products/21801">
      <b>GNSS Multi-Band L1/L2/L5 Surveying Antenna - TNC (SPK6618H)</b>
      <br />
      GPS-21801
    </a>
<!-- ----------WHITE SPACE BETWEEN PRODUCTS---------- -->
-   <a href="https://www.sparkfun.com/products/21257">
      <figure markdown>
        GNSS Magnetic Antenna Mount - 5/8
      <br />
      TOL-21257
    </a>
<!-- ----------WHITE SPACE BETWEEN PRODUCTS---------- -->
-   <a href="https://www.sparkfun.com/products/22197">
      <figure markdown>
        GNSS Antenna Mounting Hardware Kit
      </figure>
    </a>

    ---

    <a href="https://www.sparkfun.com/products/22197">
      <b>GNSS Antenna Mounting Hardware Kit</b>
      <br />
      KIT-22197
    </a>
<!-- ----------WHITE SPACE BETWEEN PRODUCTS---------- -->
-   <a href="https://www.sparkfun.com/products/21740">
      <figure markdown>
        Reinforced Interface Cable - SMA Male to TNC Male (10m)
      </figure>
    </a>

    ---

    <a href="https://www.sparkfun.com/products/21740">
      <b>Reinforced Interface Cable - SMA Male to TNC Male (10m)</b>
      <br />
      CAB-21740
    </a>
<!-- ----------WHITE SPACE BETWEEN PRODUCTS---------- -->

</div>

### Radios &nbsp;_(Optional)_

For users that require radios to send data wirelessly, you could use the following radios.

<!--
* [SparkFun BlueSMiRF v2 - Headers](https://www.sparkfun.com/products/23287)
* [SiK Telemetry Radio V3 - 915MHz, 100mW [WRL-19032]](https://www.sparkfun.com/products/19032)
* [SparkFun LoRaSerial Kit - 915MHz (Enclosed) [WRL-20029]](https://www.sparkfun.com/products/20029)
-->

<div class="grid cards col-4" markdown>
<!-- ----------WHITE SPACE BETWEEN PRODUCTS---------- -->
-   <a href="https://www.sparkfun.com/products/23287">
      <figure markdown>
        SparkFun BlueSMiRF v2 - Headers
      </figure>
    </a>

    ---

    <a href="https://www.sparkfun.com/products/23287">
      <b>SparkFun BlueSMiRF v2 - Headers</b>
      <br />
      WRL-23287
    </a>
<!-- ----------WHITE SPACE BETWEEN PRODUCTS---------- -->
-   <a href="https://www.sparkfun.com/products/19032">
      <figure markdown>
        SiK Telemetry Radio V3 - 915MHz, 100mW
      </figure>
    </a>

    ---

    <a href="https://www.sparkfun.com/products/19032">
      <b>SiK Telemetry Radio V3 - 915MHz, 100mW</b>
      <br />
      WRL-19032
    </a>
<!-- ----------WHITE SPACE BETWEEN PRODUCTS---------- -->
-   <a href="https://www.sparkfun.com/products/20029">
      <figure markdown>
        SparkFun LoRaSerial Kit - 915MHz (Enclosed)
      </figure>
    </a>

    ---

    <a href="https://www.sparkfun.com/products/20029">
      <b>SparkFun LoRaSerial Kit - 915MHz (Enclosed)</b>
      <br />
      WRL-20029
    </a>
<!-- ----------WHITE SPACE BETWEEN PRODUCTS---------- -->

</div>

### Tools &nbsp;_(Optional)_

You will need a soldering iron, solder, and [general soldering accessories](https://www.sparkfun.com/categories/49) for a secure connection when using the plated through holes. You will also need a hobby knife to disable the UART connection between the CH340 and the NEO-F10N.

<!--
* [PINECIL Soldering Iron Kit [TOL-24063]](https://www.sparkfun.com/products/24063)
* [Solder Lead Free - 15-gram Tube [TOL-9163]](https://www.sparkfun.com/products/9163)
* [Flush Cutters - Xcelite [TOL-14782]](https://www.sparkfun.com/products/14782)
* [Hook-Up Wire - Assortment (Stranded, 22 AWG) [PRT-11375]](https://www.sparkfun.com/products/11375)
* [Wire Stripper - 20-30 AWG Solid (22-32 AWG Stranded) [TOL-22263]](https://www.sparkfun.com/products/22263)
* [Hobby Knife [TOL-09200]](https://www.sparkfun.com/products/9200)
-->

<div class="grid cards col-4" markdown>

-   <a href="https://www.sparkfun.com/products/24063">
      <figure markdown>
        PINECIL Soldering Iron Kit
      </figure>
    </a>

    ---

    <a href="https://www.sparkfun.com/products/24063">
      <b>PINECIL Soldering Iron Kit</b>
      <br />
      TOL-24063
    </a>
<!-- ----------WHITE SPACE BETWEEN PRODUCTS---------- -->
-   <a href="https://www.sparkfun.com/products/9163">
      <figure markdown>
        Solder Lead Free - 15-gram Tube
      </figure>
    </a>

    ---

    <a href="https://www.sparkfun.com/products/9163">
      <b>Solder Lead Free - 15-gram Tube</b>
      <br>
      TOL-09163
    </a>
<!-- ----------WHITE SPACE BETWEEN PRODUCTS---------- -->
-   <a href="https://www.sparkfun.com/products/11375">
      <figure markdown>
        Hook-Up Wire - Assortment (Stranded, 22 AWG)
      </figure>
    </a>

    ---

    <a href="https://www.sparkfun.com/products/11375">
      <b>Hook-Up Wire - Assortment (Stranded, 22 AWG)</b>
      <br />
      PRT-11375
    </a>
<!-- ----------WHITE SPACE BETWEEN PRODUCTS---------- -->
-   <a href="https://www.sparkfun.com/products/24771">
      <figure markdown>
        Wire Strippers - 20-30 AWG
      </figure>
    </a>

    ---

    <a href="https://www.sparkfun.com/products/24771">
      <b>Wire Strippers - 20-30 AWG</b>
      <br />
      TOL-24771
    </a>
<!-- ----------WHITE SPACE BETWEEN PRODUCTS---------- -->
-   <a href="https://www.sparkfun.com/products/14782">
      <figure markdown>
        Flush Cutters - Xcelite
      </figure>
    </a>

    ---

    <a href="https://www.sparkfun.com/products/14782">
      <b>Flush Cutters - Xcelite</b>
      <br />
      TOL-14782
    </a>
<!-- ----------WHITE SPACE BETWEEN PRODUCTS---------- -->

-   <a href="https://www.sparkfun.com/products/9200">
      <figure markdown>
        Hobby Knife
      </figure>
    </a>

    ---

    <a href="https://www.sparkfun.com/products/9200">
      <b>Hobby Knife</b>
      <br />
      TOL-09200
    </a>
<!-- ----------WHITE SPACE BETWEEN PRODUCTS---------- -->
</div>

### Prototyping Accessories &nbsp;_(Optional)_

For those using radios to connect a base station and rover together, you will need to connect to the PTHs. You could use IC hooks for a temporary connection depending on your setup and what you have available. Of course, you will want to the solder header pins for a secure connection. Below are a few prototyping accessories that you may want to consider.

<!--
* [Breadboard - Self-Adhesive (White) [PRT-12002]](https://www.sparkfun.com/products/12002)
* [IC Hook with Pigtail [CAB-09741]](https://www.sparkfun.com/products/9741)
* [Break Away Headers - Straight [PRT-00116]](https://www.sparkfun.com/products/116)
* [Female Headers [PRT-00115]](https://www.sparkfun.com/products/115)
* [Header - 6-pin Female (PTH, 0.1") [PRT-11894]](https://www.sparkfun.com/products/11894)
* [Jumper Wires Premium 6" M/M Pack of 10 [PRT-08431]](https://www.sparkfun.com/products/8431)
-->

<div class="grid cards col-4" markdown>
<!-- ----------WHITE SPACE BETWEEN PRODUCTS---------- -->
-   <a href="https://www.sparkfun.com/products/12002">
      <figure markdown>
        Breadboard - Self-Adhesive (White)
      </figure>
    </a>

    ---

    <a href="https://www.sparkfun.com/products/12002">
      <b>Breadboard - Self-Adhesive (White)</b>
      <br />
      PRT-12002
    </a>
<!-- ----------WHITE SPACE BETWEEN PRODUCTS---------- -->
-   <a href="https://www.sparkfun.com/products/9741">
      <figure markdown>
        IC Hook with Pigtail
      </figure>
    </a>

    ---

    <a href="https://www.sparkfun.com/products/9741">
      <b>IC Hook with Pigtail</b>
      <br>
      CAB-09741
    </a>
<!-- ----------WHITE SPACE BETWEEN PRODUCTS---------- -->
-   <a href="https://www.sparkfun.com/products/116">
      <figure markdown>
        Break Away Headers - Straight
      </figure>
    </a>

    ---

    <a href="https://www.sparkfun.com/products/116">
      <b>Break Away Headers - Straight</b>
      <br />
      PRT-00116
    </a>
<!-- ----------WHITE SPACE BETWEEN PRODUCTS---------- -->
-   <a href="https://www.sparkfun.com/products/115">
      <figure markdown>
        Female Headers
      </figure>
    </a>

    ---

    <a href="https://www.sparkfun.com/products/115">
      <b>Female Headers</b>
      <br />
      PRT-00115
    </a>
<!-- ----------WHITE SPACE BETWEEN PRODUCTS---------- -->
-   <a href="https://www.sparkfun.com/products/11894">
      <figure markdown>
        Header - 6-pin Female (PTH, 0.1
      <br />
      PRT-11894
    </a>
<!-- ----------WHITE SPACE BETWEEN PRODUCTS---------- -->
-   <a href="https://www.sparkfun.com/products/8431">
      <figure markdown>
        Jumper Wires Premium 6
      <br />
      PRT-08431
    </a>
<!-- ----------WHITE SPACE BETWEEN PRODUCTS---------- -->
</div>

### Suggested Reading

If you aren’t familiar with the following concepts, we also recommend checking out a few of these tutorials before continuing.

<div class="grid cards col-4" markdown>
<!-- ----------WHITE SPACE BETWEEN GRID CARDS---------- -->
-   <a href="https://learn.sparkfun.com/tutorials/9">
      <figure markdown>
        GPS Basics
      </figure>
    </a>

    ---

    <a href="https://learn.sparkfun.com/tutorials/9">
      <b>GPS Basics</b>
    </a>
<!-- ----------WHITE SPACE BETWEEN GRID CARDS---------- -->
-   <a href="https://learn.sparkfun.com/tutorials/how-to-install-ch340-drivers/all">
      <figure markdown>
        How to Install CH340 Drivers
      </figure>
    </a>

    ---

    <a href="https://learn.sparkfun.com/tutorials/how-to-install-ch340-drivers/all">
      <b>How to Install CH340 Drivers</b>
    </a>
<!-- ----------WHITE SPACE BETWEEN GRID CARDS---------- -->
-   <a href="https://learn.sparkfun.com/tutorials/getting-started-with-u-center-for-u-blox">
      <figure markdown>
        Getting Started with U-Center for u-blox
      </figure>
    </a>

    ---

    <a href="https://learn.sparkfun.com/tutorials/getting-started-with-u-center-for-u-blox">
      <b>Getting Started with U-Center for u-blox</b>
    </a>
<!-- ----------WHITE SPACE BETWEEN GRID CARDS---------- -->
-   <a href="https://learn.sparkfun.com/tutorials/how-to-upgrade-firmware-of-a-u-blox-gnss-receiver">
      <figure markdown>
        How to Upgrade Firmware of a u-blox GNSS Receiver
      </figure>
    </a>

    ---

    <a href="https://learn.sparkfun.com/tutorials/how-to-upgrade-firmware-of-a-u-blox-gnss-receiver">
      <b>How to Upgrade Firmware of a u-blox GNSS Receiver</b>
    </a>
<!-- ----------WHITE SPACE BETWEEN GRID CARDS---------- -->
-   <a href="https://learn.sparkfun.com/tutorials/serial-communication">
      <figure markdown>
        Serial Communication
      </figure>
    </a>

    ---

    <a href="https://learn.sparkfun.com/tutorials/serial-communication">
      <b>Serial Communication</b>
    </a>
<!-- ----------WHITE SPACE BETWEEN GRID CARDS---------- -->
-   <a href="https://learn.sparkfun.com/tutorials/how-to-work-with-jumper-pads-and-pcb-traces/introduction">
      <figure markdown>
        How to Work with Jumper Pads and PCB Traces
      </figure>
    </a>

    ---

    <a href="https://learn.sparkfun.com/tutorials/how-to-work-with-jumper-pads-and-pcb-traces/introduction">
      <b>How to Work with Jumper Pads and PCB Traces</b>
    </a>
<!-- ----------WHITE SPACE BETWEEN GRID CARDS---------- -->
-   <a href="https://learn.sparkfun.com/tutorials/how-to-solder-through-hole-soldering">
      <figure markdown>
        How to Solder: Through-Hole Soldering
      </figure>
    </a>

    ---

    <a href="https://learn.sparkfun.com/tutorials/how-to-solder-through-hole-soldering">
      <b>How to Solder: Through-Hole Soldering</b>
    </a>
<!-- ----------WHITE SPACE BETWEEN GRID CARDS---------- -->
-   <a href="https://learn.sparkfun.com/tutorials/installing-arduino-ide">
      <figure markdown>
        Installing Arduino IDE
      </figure>
    </a>

    ---

    <a href="https://learn.sparkfun.com/tutorials/installing-arduino-ide">
      <b>Installing Arduino IDE</b>
    </a>
<!-- ----------WHITE SPACE BETWEEN GRID CARDS---------- -->
-   <a href="https://learn.sparkfun.com/tutorials/installing-board-definitions-in-the-arduino-ide">
      <figure markdown>
        Installing Board Definitions in the Arduino IDE
      </figure>
    </a>

    ---

    <a href="https://learn.sparkfun.com/tutorials/installing-board-definitions-in-the-arduino-ide">
      <b>Installing Board Definitions in the Arduino IDE</b>
    </a>
<!-- ----------WHITE SPACE BETWEEN GRID CARDS---------- -->
-   <a href="https://learn.sparkfun.com/tutorials/iot-redboard-esp32-development-board-hookup-guide">
      <figure markdown>
        IoT RedBoard ESP32 Development Board Hookup Guide
      </figure>
    </a>

    ---

    <a href="https://learn.sparkfun.com/tutorials/iot-redboard-esp32-development-board-hookup-guide">
      <b>IoT RedBoard ESP32 Development Board Hookup Guide</b>
    </a>
<!-- ----------WHITE SPACE BETWEEN GRID CARDS---------- -->
</div>

You may also be interested in the following blog posts on GNSS technologies.

<div class="grid cards col-4" markdown align="center">

-   <a href="https://www.sparkfun.com/news/4276">
	<figure markdown>
	Tutorial Thumbnail
	</figure>

	---

	**GPS vs GNSS**</a>
</div>

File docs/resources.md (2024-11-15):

Now that you've successfully got your SparkFun GNSS-RTK L1/L5 Breakout - NEO-F10N, SMA up and running, it's time to incorporate it into your own project! For more information, check out the resources below:

**SparkFun Resources**

* [Schematic (PDF)](../assets/board_files/SparkFun_GNSS_L1_L5_BreakoutNEO-F10N_Schematic_V10.pdf)
* [KiCad Files (ZIP)](../assets/board_files/SparkFun_NEO-F10N_v10.zip)
* [3D Model (STEP)](../assets/3d_model/SparkFun_NEO-F10N_3D_model.step)
* [Board Dimensions (PNG)](../assets/img/SparkFun_NEO-F10N-Board_Dimensions.jpg)
* [Building a GPS System](https://www.sparkfun.com/gps)
* [Arduino Library](https://github.com/sparkfun/SparkFun_u-blox_GNSS_v3)
* [GitHub Hardware Repo](https://github.com/sparkfun/SparkFun_u-blox_NEO-F10N)

**u-blox NEO-F10N Resources**

* [Product Summary (PDF)](../assets/component_documentation/NEO-F10N_ProductSummary_UBX-22038758.pdf)
* [Datasheet (PDF)](../assets/component_documentation/NEO-F10N_DataSheet_UBX-23002117.pdf)
* [Integration Manual (PDF)](../assets/component_documentation/NEO-F10N_IntegrationManual_UBXDOC-963802114-12193.pdf)
* [Interface Description (PDF)](../assets/component_documentation/u-blox-F10-SPG-6.00_InterfaceDescription_UBX-23002975.pdf)
* [White Paper: Modern GNSS/GPS signals: Moving from Single-Band to Dual-Band (PDF)](../assets/component_documentation/GPS-signals-migration-wp.pdf)
* [u-blox ECCN (PDF)](../assets/component_documentation/Ublox_ECCN.pdf)

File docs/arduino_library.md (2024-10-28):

!!! arduino
    This example assumes you are using the latest version of the Arduino IDE on your desktop. If this is your first time using the Arduino IDE, library, or board add-on, please review the following tutorials.

    - [Installing the Arduino IDE](https://learn.sparkfun.com/tutorials/installing-arduino-ide)
    - [Installing Board Definitions in the Arduino IDE](https://learn.sparkfun.com/tutorials/installing-board-definitions-in-the-arduino-ide)
    - [Installing an Arduino Library](https://learn.sparkfun.com/tutorials/installing-an-arduino-library)

!!! note
    If you've never connected an CH340 device to your computer before, you may need to install drivers for the USB-to-serial converter. Check out our section on "[How to Install CH340 Drivers](https://learn.sparkfun.com/tutorials/how-to-install-ch340-drivers)" for help with the installation.

    - [How to Install CH340 Drivers](https://learn.sparkfun.com/tutorials/how-to-install-ch340-drivers/all)

SparkFun has written a library to work with the u-blox NEO-F10N. You can obtain this library through the Arduino Library Manager by searching for "**SparkFun u-blox GNSS v3**". Find the one written by SparkFun Electronics and install the latest version. Users who prefer to manually install the library can get it from the [GitHub Repository](https://github.com/sparkfun/SparkFun_u-blox_GNSS_v3) or download the .ZIP by clicking the button below:

<div style="text-align: center"><a href="https://github.com/sparkfun/SparkFun_u-blox_GNSS_v3/archive/refs/heads/main.zip" class="md-button">SparkFun u-blox GNSS Arduino Library - v3 (ZIP)</a></div>

 Once you have the library installed checkout the various examples! There are several examples in the library that cover more than just the NEO-F10N. Note that some examples will not apply depending on the modules features. We will be looking at the [NEO-F10N folder](https://github.com/sparkfun/SparkFun_u-blox_GNSS_v3/tree/main/examples/NEO-F10N).

!!! note
    According to the u-blox Integration Manual for the NEO-F10N, the current firmware does not support such as geofencing and low power mode so those examples contained in the library do not apply. Remember, the NEO-F10N only supports serial UART so the examples involving I<sup>2</sup>C and SPI do not apply either.

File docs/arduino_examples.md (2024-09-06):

Now that we have our library and board add-on installed, we can start experimenting with the breakout board. For the scope of this tutorial, we will highlight one of the examples to get started. From there we will be able to build our own custom code to integrate the development board into a project.

### Example 1: NAV-SIG

This example shows how to configure the NEO-F10N GNSS for L5 band and overriding the health status. The output will indicate the type of signals that the NEO-F10N is receiving. Head to the example in the **NEO-10N** folder (located in **File** **Examples** > **SparkFun u-blox GNSS V3** > **NEO-F10N** > **Example1_NAV-SIG**).

If you have not already, select your Board (in this case the **SparkFun ESP32 IoT RedBoard**), and associated COM port. Upload the code to the board and set the [Arduino Serial Monitor](https://learn.sparkfun.com/tutorials/terminal-basics/all#arduino-serial-monitor-windows-mac-linux) to **115200** baud. Give the NEO-F10N a few minutes to get a satellite lock. The signals available will be output in the Serial Monitor. If everything goes well, you should see some L5 signals (highlighted in red).

<div style="text-align: center;">
  <table>
    <tr style="vertical-align:middle;">
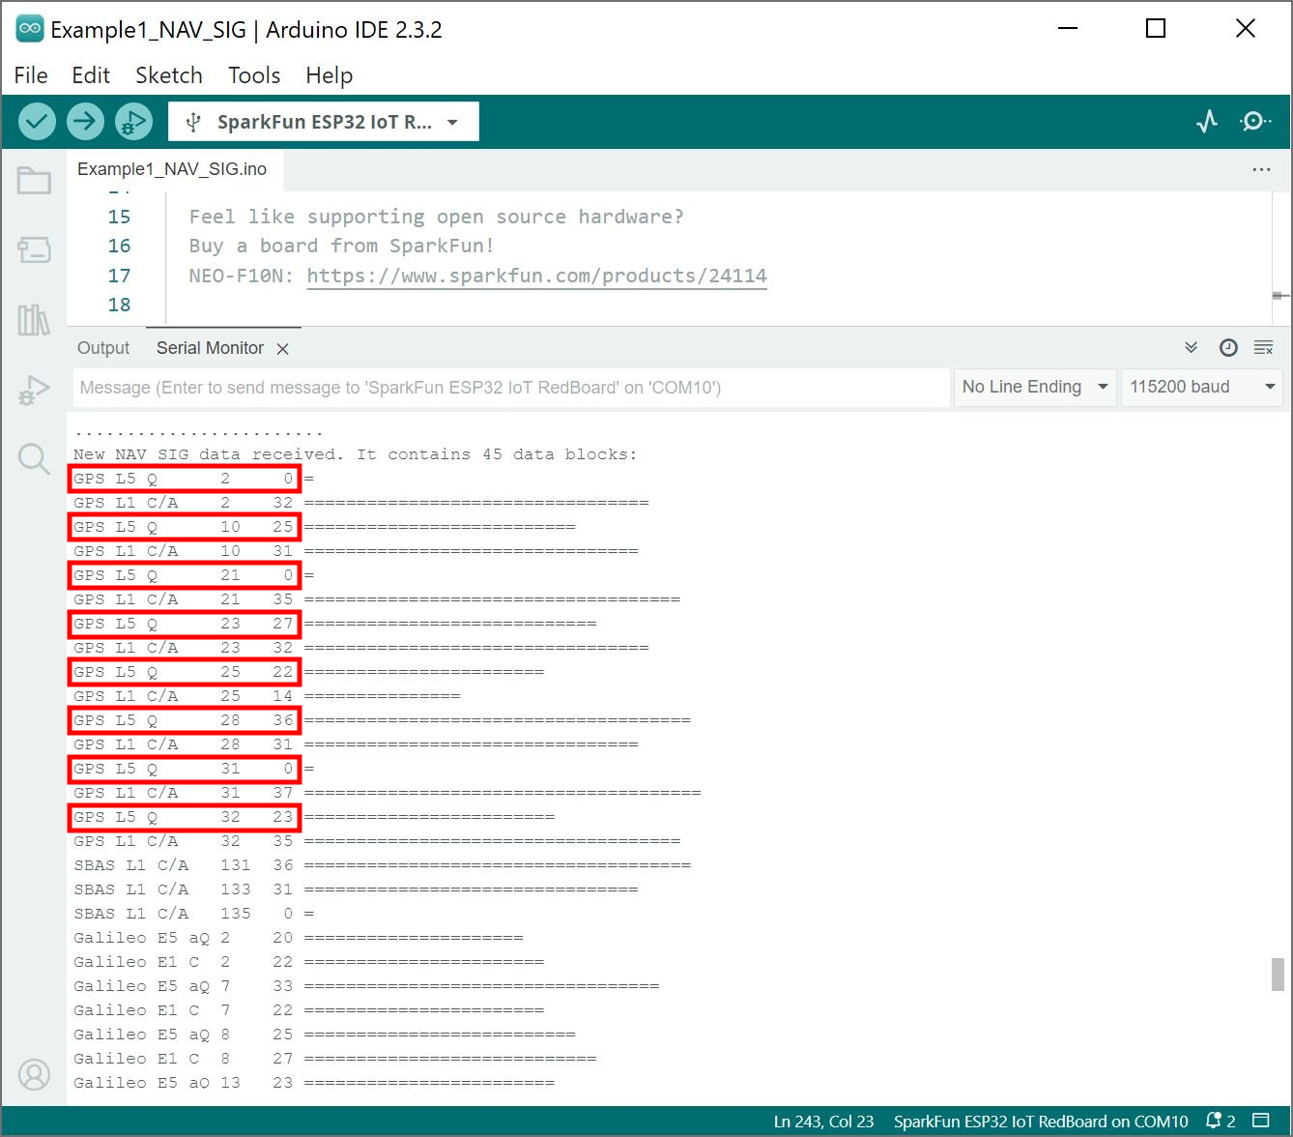
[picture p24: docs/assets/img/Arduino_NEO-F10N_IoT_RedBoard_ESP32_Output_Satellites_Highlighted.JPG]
NEO-F10N Signals and Health Status; L5 Highlighted
     <td style="text-align: center; vertical-align: middle;"></td>
    </tr>
  </table>
</div>

### Example 12: Use UART

!!! note
    Make sure that you have the latest version of the SparkFun u-blox GNSS v3 Arduino Library when using the "Use UART" example. You will need a microcontroller (e.g. ESP32) with enough memory to compile this example.  Depending on the microcontroller that you use, you may also need to adjust the defined serial port from `Serial2` to `Serial1`.

This example shows how to output your coordinates and satellites in view through the Serial UART. Head to the example in the **NEO-10N** folder (located in **File** **Examples** > **SparkFun u-blox GNSS V3** > **Basics** > **Example12_UseUart**).

If you have not already, select your Board (in this case the **SparkFun ESP32 IoT RedBoard**), and associated COM port. Upload the code to the board and set the [Arduino Serial Monitor](https://learn.sparkfun.com/tutorials/terminal-basics/all#arduino-serial-monitor-windows-mac-linux) to **115200** baud. Once there are enough satellites in view you should be able to see your coordinates and the number of satellites in view!

<div style="text-align: center;">
  <table>
    <tr style="vertical-align:middle;">
     <td style="text-align: center; vertical-align: middle;"><a href="../assets/img/Arduino_NEO-F10N_IoT_RedBoard_ESP32_Output_Coordinates_SIV.JPG">Coordinates Shown in the Arduino Serial Monitor with the NEO-F10N</a></td>
    </tr>
  </table>
</div>

### More Examples!

Now that you got it up and running, check out the SparkFun u-blox Arduino Library for other UART examples!

<div style="text-align: center"><a href="https://github.com/sparkfun/SparkFun_u-blox_GNSS_v3/tree/main/examples" target="github_gnss_v3" class="md-button">SparkFun_u-blox_GNSS_v3 > examples</a></div>

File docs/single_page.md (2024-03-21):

---
hide:
  - navigation
  - toc
icon: fontawesome/solid/scroll
---

# Introduction
--8<-- "./docs/introduction.md"

# Hardware Overview
--8<-- "./docs/hardware_overview.md"

# Hardware Hookup
--8<-- "./docs/hardware_hookup.md"

# Installing the Arduino Library
--8<-- "./docs/arduino_library.md"

# Enabling L5 Band and Overriding Health Status
--8<-- "./docs/enable_l5_band_and_override_health_status.md"

# Arduino Examples
--8<-- "./docs/arduino_examples.md"

# Troubleshooting
--8<-- "./docs/troubleshooting.md"

# Resources
--8<-- "./docs/resources.md"

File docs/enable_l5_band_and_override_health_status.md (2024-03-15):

By default, the L5 band is disabled on the NEO-F10N. To take advantage of the L5 band, you will need to:

* enable the L5 band
* override the health status check
* save the settings into memory
* perform a software reset

### Configuring with the Arduino Library

!!! arduino
    Make sure that you are using the SparkFun u-blox GNSS Arduino Library **v3.1.1+** in order to be able to take advantage of the following functions.

To do this using the Arduino Library, users can add   `myGNSS.setVal8(UBLOX_CFG_SIGNAL_GPS_L5_ENA, 1)`, `myGNSS.setGPSL5HealthOverride(true)`, and `myGNSS.softwareResetGNSSOnly()` in the `setup()` function after connecting an Arduino to the NEO-F10N's hardware UART. You will notice this at the end of the `setup()` function under the **Example1_NAV_SIG.ino** example.

```c
  myGNSS.setUART1Output(COM_TYPE_UBX); //Set the UART1 port to output UBX only (turn off NMEA noise)
  myGNSS.saveConfigSelective(VAL_CFG_SUBSEC_IOPORT); //Save (only) the communications port settings to flash and BBR

  myGNSS.setMeasurementRate(5000); //Produce one solution every five seconds (NAV SIG produces a _lot_ of data!)

  myGNSS.setVal8(UBLOX_CFG_SIGNAL_GPS_L5_ENA, 1); // Make sure the GPS L5 band is enabled (needed on the NEO-F9P)

  myGNSS.setGPSL5HealthOverride(true); // Mark L5 signals as healthy - store in RAM and BBR

  myGNSS.setLNAMode(SFE_UBLOX_LNA_MODE_NORMAL); // Set the LNA gain to normal (full). Other options: LOWGAIN, BYPASS

  myGNSS.softwareResetGNSSOnly(); // Restart the GNSS to apply the L5 health override

  myGNSS.setAutoNAVSIGcallbackPtr(&newSIG); // Enable automatic NAV SIG messages with callback to newSIG
```

### Configuring with U-Center

Users can also enable the L5 band via U-Center v22.07. Connect a USB cable between the NEO-F10N breakout board and your computer. Then open the software, connect to the COM port that the board enumerated to, and head to **View** > **Generation 9 Configuration View**. Once open, select the check box for GPS's **L5**. Select the check box for **BBR** and **Flash**. When ready, hit the **Send Configuration** button.

<div style="text-align: center;">
  <table>
    <tr style="vertical-align:middle;">
     <td style="text-align: center; vertical-align: middle;"><a href="../assets/img/u-center_enable_L5_Highlighted.jpg">Enable L5 Band with U-Center</a></td>
    </tr>
  </table>
</div>

To override the health status by heading to **View** > **Messages View** > **CUSTOM**. With the Custom Messages set for **Hex**, paste the following to configure the settings in **BBR** and hit the send button:

``` bash
B5 62 06 8A 09 00 01 02 00 00 01 00 32 10 01 E0 FE
```

<div style="text-align: center;">
  <table>
    <tr style="vertical-align:middle;">
     <td style="text-align: center; vertical-align: middle;"><a href="../assets/img/u-center_L5_Health_Status_BBR.JPG">Override Health Status L5 Band Configured in BBR</a></td>
    </tr>
  </table>
</div>

Then send the following to configure the settings in **FLASH** and hit the send button:

``` bash
B5 62 06 8A 09 00 01 04 00 00 01 00 32 10 01 E2 0E
```

<div style="text-align: center;">
  <table>
    <tr style="vertical-align:middle;">
     <td style="text-align: center; vertical-align: middle;"><a href="../assets/img/u-center_L5_Health_Status_Flash.JPG">Override Health Status L5 Band Configured in Flash</a></td>
    </tr>
  </table>
</div>

!!! tip
    To confirm that the above UBX messages were sent successfully, check the `UBX-ACK-ACK` messages after sending the message. For users that want to revert to the default behavior, make sure to check the **[NEO-F10N Integration Manual under "2.1.4 GPS L5 signal health status configuration" section](../assets/component_documentation/NEO-F10N_IntegrationManual_UBXDOC-963802114-12193.pdf)** page 10 under *Table 5: UBX binary strings to revert the GPS L5 signal health status monitoring to default*.

Ensure that the configuration is saved in BBR and Flash using the UBX-CFG-VALSET. Then send a UBX-CFG-RST message with resetMode 0x01 to apply the configuration stored in the BBR and flash layers.

The "Satellite Level History" window should update and include the L5 bands if it is available.

<div style="text-align: center;">
  <table>
    <tr style="vertical-align:middle;">
     <td style="text-align: center; vertical-align: middle;"><a href="../assets/img/U-Center_L5_Band_Satellite_Level_History-Highlighted.JPG">L5 Band Displaying in Satellite Level History with U-Center</a></td>
    </tr>
  </table>
</div>

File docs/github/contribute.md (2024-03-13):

# Contribute: Help Fix our Mistake!
Spot something wrong? Feel free to contribute our open-source design and documentation. 

## Improve our Documentation
All of this documentation can be modified by you! Please help us make it better.

* These pages are contained in the [`docs` folder of the SparkFun GNSS-RTK L1/L5 Breakout - NEO-F10N repository](https://github.com/sparkfun/SparkFun_u-blox_NEO-F10N/tree/main/docs).

### Submit a Correction
1. Fork this repo
2. Add your corrections or improvements to the markdown file
3. File a pull request with your changes, and enjoy making the ~~words~~ ~~worlds~~ world a better place.
    * Once received, the documentation specialist will automatically be notified.
    * We will review your suggested improvements to make sure they are correct and fit within our documentation standards.

## Improve our Hardware Design
All of our designs are open-source! Please help us make it better.

* Our board design files are contained in the [`Hardware` folder of the SparkFun GNSS-RTK L1/L5 Breakout - NEO-F10N repository](https://github.com/sparkfun/SparkFun_u-blox_NEO-F10N/tree/main/Hardware).

### Submit a Design Improvement
1. Fork this repo
2. Add your design improvements
3. File a pull request with your changes, and enjoy making the ~~words~~ ~~worlds~~ world a better place.
    * Once received, the engineer in charge of the original design will automatically be notified.
    * We will review your suggested improvements, if they are within our board design standards and meet our product design requirements, we will flag these changes for our next board revision. *(Please note, that even if your suggestion is accepted, these changes may not be immediate. We may have to cycle through our current product inventory first.)*

## Contributors
Let's provided some recognition to the contributors for this project!

GitHub Contributors Image
<br>


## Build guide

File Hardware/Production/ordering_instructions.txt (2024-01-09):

Ordering Instructions:
Panel dimensions: 174.72 x 90.40 mm.
Material: TG155
Solder Mask: Red
Silkscreen: White
Layers: 2
Finish: HASL Lead-Free
Thickness: 1.6mm
Copper weight: 1oz
Minimum track width: 0.15mm (6.00mil)
Minimum via drill: 0.30mm (11.81mil)

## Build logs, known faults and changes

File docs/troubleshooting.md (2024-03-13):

### General Troubleshooting Help

!!! note
    <span class="glyphicon glyphicon-question-sign" aria-hidden="true"></span>
        <strong> Not working as expected and need help? </strong> <br /><br />

    If you need technical assistance and more information on a product that is not working as you expected, we recommend heading on over to the <a href="https://www.sparkfun.com/technical_assistance">SparkFun Technical Assistance</a> page for some initial troubleshooting. <br /><br />

    <div style="text-align: center"><a href="https://www.sparkfun.com/technical_assistance" target="sfe_technical_assistance" class="md-button">SparkFun Technical Assistance Page</a></div>

    If you don't find what you need there, the <a href="https://forum.sparkfun.com/">SparkFun Forums</a> are a great place to find and ask for help. If this is your first visit, you'll need to <a href="https://forum.sparkfun.com/ucp.php?mode=register">create a Forum Account</a> to search product forums and post questions.<br /><br />

    <div style="text-align: center"><a href="https://forum.sparkfun.com/ucp.php?mode=register" class="md-button">Create New Forum Account</a>&nbsp;&nbsp;&nbsp;<a href="https://forum.sparkfun.com/viewforum.php?f=180" class="md-button md-button--primary">Log Into SparkFun Forums</a></div>

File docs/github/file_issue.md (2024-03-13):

# Did we make a mistake?

Spot something wrong? Please let us know. 

!!! attention
    This is not where customers should seek assistance on a product. If you require technical assistance or have questions about a product that is not working as expected, please head over to the [SparkFun Technical Assistance](https://www.sparkfun.com/technical_assistance) page for some initial troubleshooting.
    <center>
    [SparkFun Technical Assistance Page](https://www.sparkfun.com/technical_assistance){ .md-button .md-button--primary }
    </center>

    If you can't find what you need there, you'll need a [Forum Account](https://forum.sparkfun.com/ucp.php?mode=register) to search product forums and post questions.

## Discrepancies in the Documentation

All of this documentation can be modified by you! Please help us make it better.

* The documentation files for these pages are contained in the [`docs` folder of the SparkFun GNSS-RTK L1/L5 Breakout - NEO-F10N repository](https://github.com/sparkfun/SparkFun_u-blox_NEO-F10N/tree/main/docs).

### Spot something wrong?
If a section of the documentation is incorrect, please [open an issue](https://github.com/sparkfun/SparkFun_u-blox_NEO-F10N/issues) and let us know.

### Do you have a suggested correction?
1. With a GitHub account, fork this repo
2. Add your correction(s) or improvement(s) to the markdown file(s)
3. File a pull request with your changes, and enjoy making the ~~words~~ ~~worlds~~ world a better place.
    * Once received, the documentation specialist will automatically be notified.
    * We will review your suggested improvement(s) to make sure they are correct and fit within our documentation standards.

## Problems in the Hardware Design

All of our designs are open-source! Please help us make it better.

* Our board design files are contained in the [`Hardware` folder of the SparkFun GNSS-RTK L1/L5 Breakout - NEO-F10N repository](https://github.com/sparkfun/SparkFun_u-blox_NEO-F10N/tree/main/Hardware).

### Does something not make sense?
If part of the design is confusing, please [open an issue](https://github.com/sparkfun/SparkFun_u-blox_NEO-F10N/issues) and let us know.

### Did we forget to include an important function of the board?
* Please keep in mind that we may intentionally exclude certain functions of the board to meet our product design requirements. *(For example, our Qwiic Micro boards are intended to fit on a small board layout and only use I<sup>2</sup>C communication; therefore, we may not have the SPI and interrupt pins available for users.)*
* If part of the board's functionality is missing, please [open an issue](https://github.com/sparkfun/SparkFun_u-blox_NEO-F10N/issues) and file a feature request.

### Do you wish to contribute directly to improving the board design?
1. With a GitHub account, Fork this repo
2. Add your design improvement(s)
3. File a pull request with your changes, and enjoy making the ~~words~~ ~~worlds~~ world a better place.
    * Once received, the engineer in charge of the original design will automatically be notified.
    * We will review your suggested improvement(s), if they are within our board design standards and meet our product design requirements, we will flag these changes for our next board revision. *(Please note, that even if your suggestion is accepted, these changes may not be immediate. We may have to cycle through our current product inventory first.)*

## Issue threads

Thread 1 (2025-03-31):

Suggestion to add PPS support over USB serial

marekm72, 2025-03-31:
Simple hardware mod - connect drain of Q1 (inverted timepulse active low that drives the D4 yellow LED) to pin 12 (DCD# input) of U8 (CH340C).  The CH340 modem control inputs have internal pull-ups, and the leading edge that matters for timing precision is the faster Q1 turn-on, so the open-drain driver works properly.  While PPS over USB serial is not as good as over a good old COM port, timing accuracy of about one millisecond (USB latency/jitter) should be achievable - better than from NMEA messages alone.  Please see the picture below for the small wire added, and consider making that connection in the next board revision.

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

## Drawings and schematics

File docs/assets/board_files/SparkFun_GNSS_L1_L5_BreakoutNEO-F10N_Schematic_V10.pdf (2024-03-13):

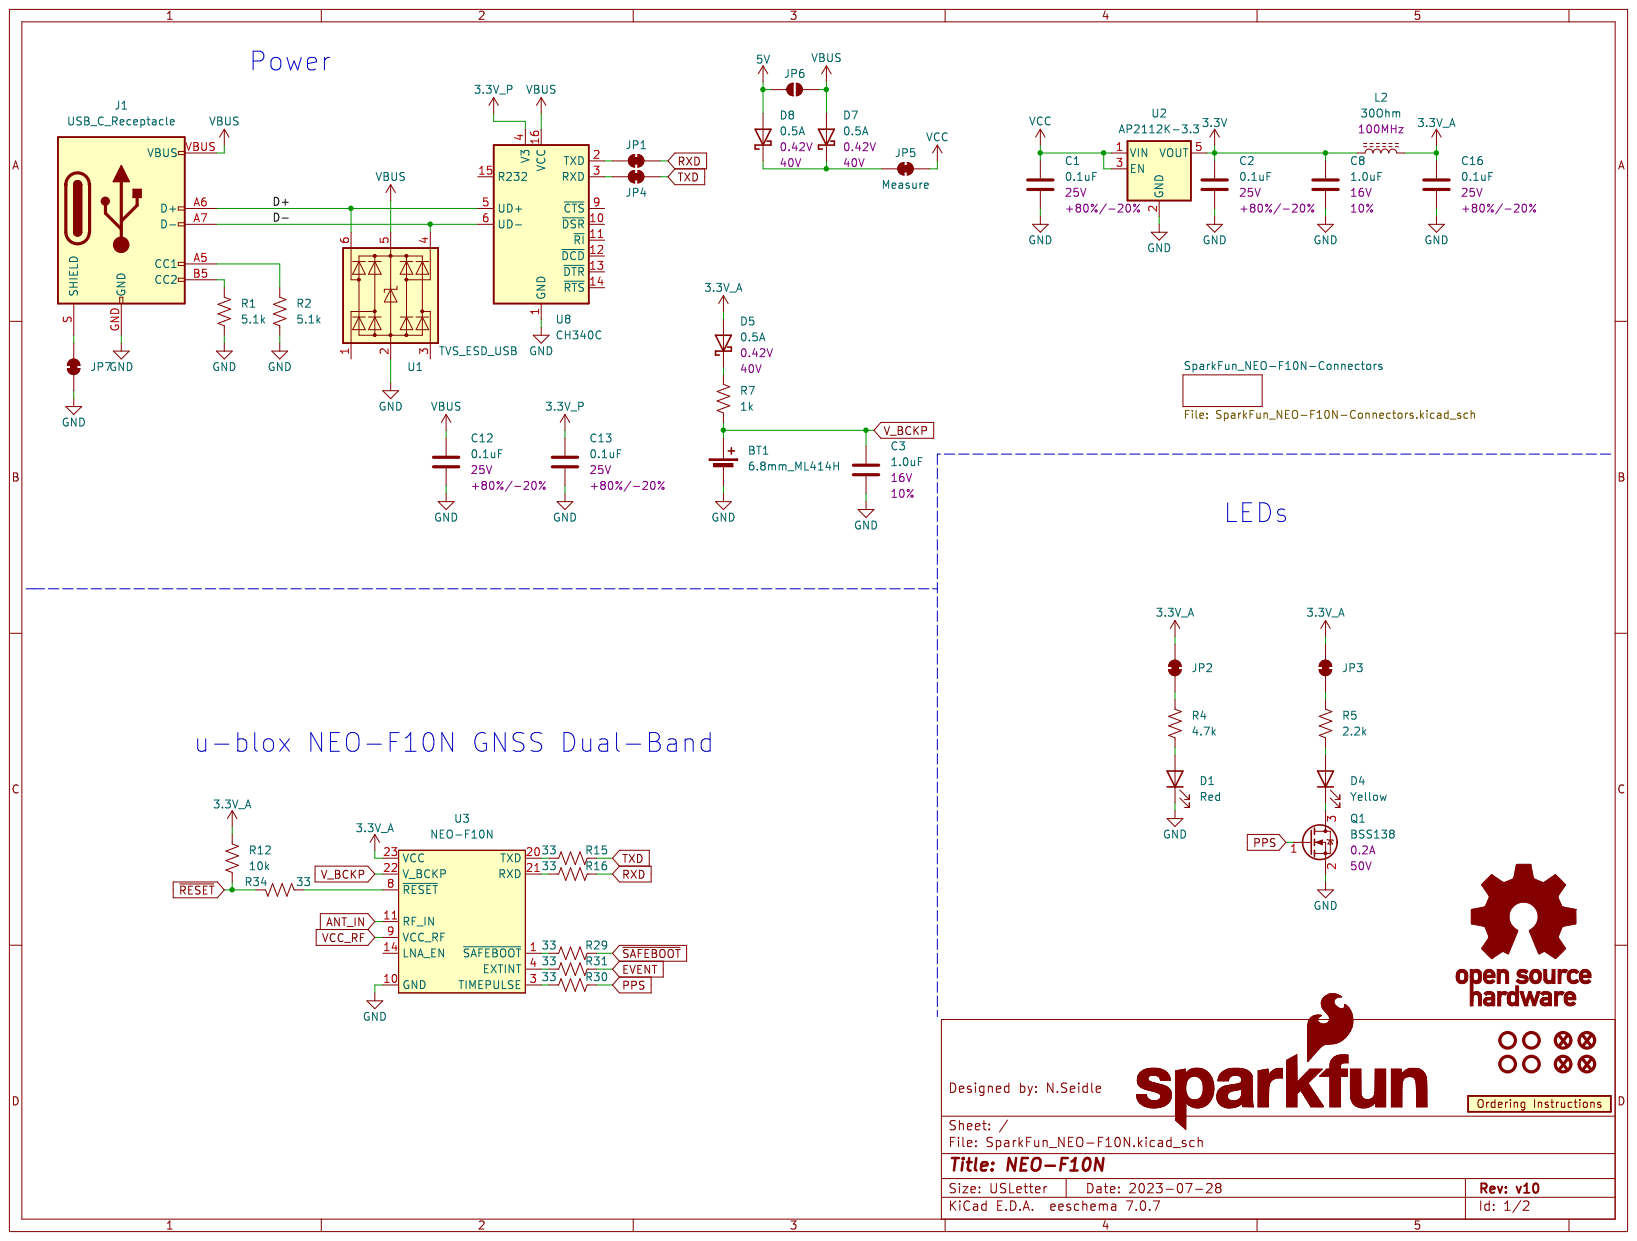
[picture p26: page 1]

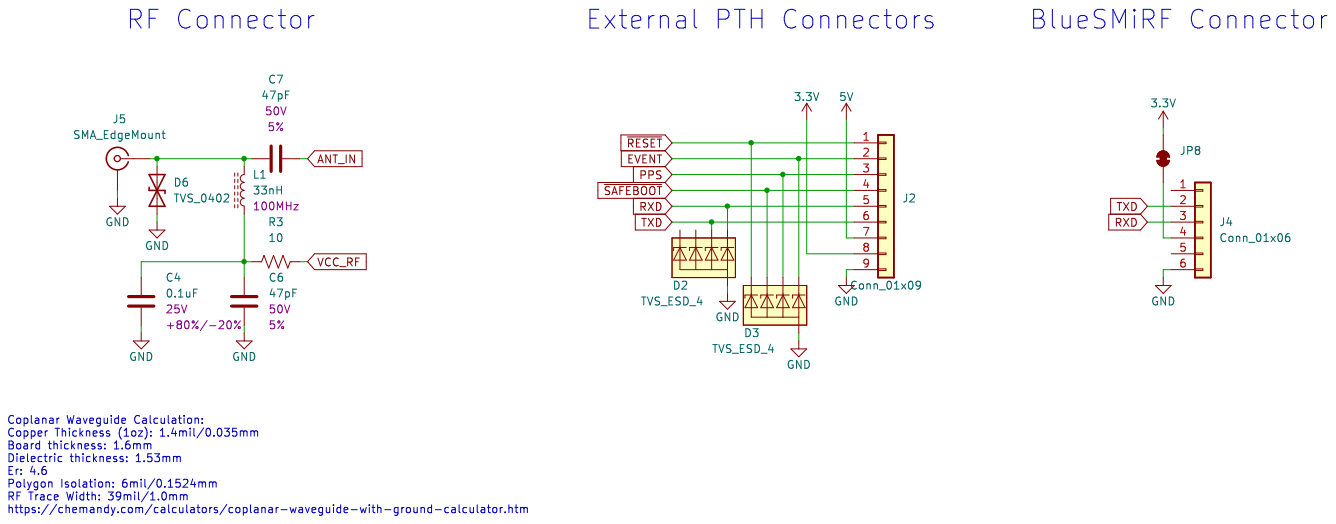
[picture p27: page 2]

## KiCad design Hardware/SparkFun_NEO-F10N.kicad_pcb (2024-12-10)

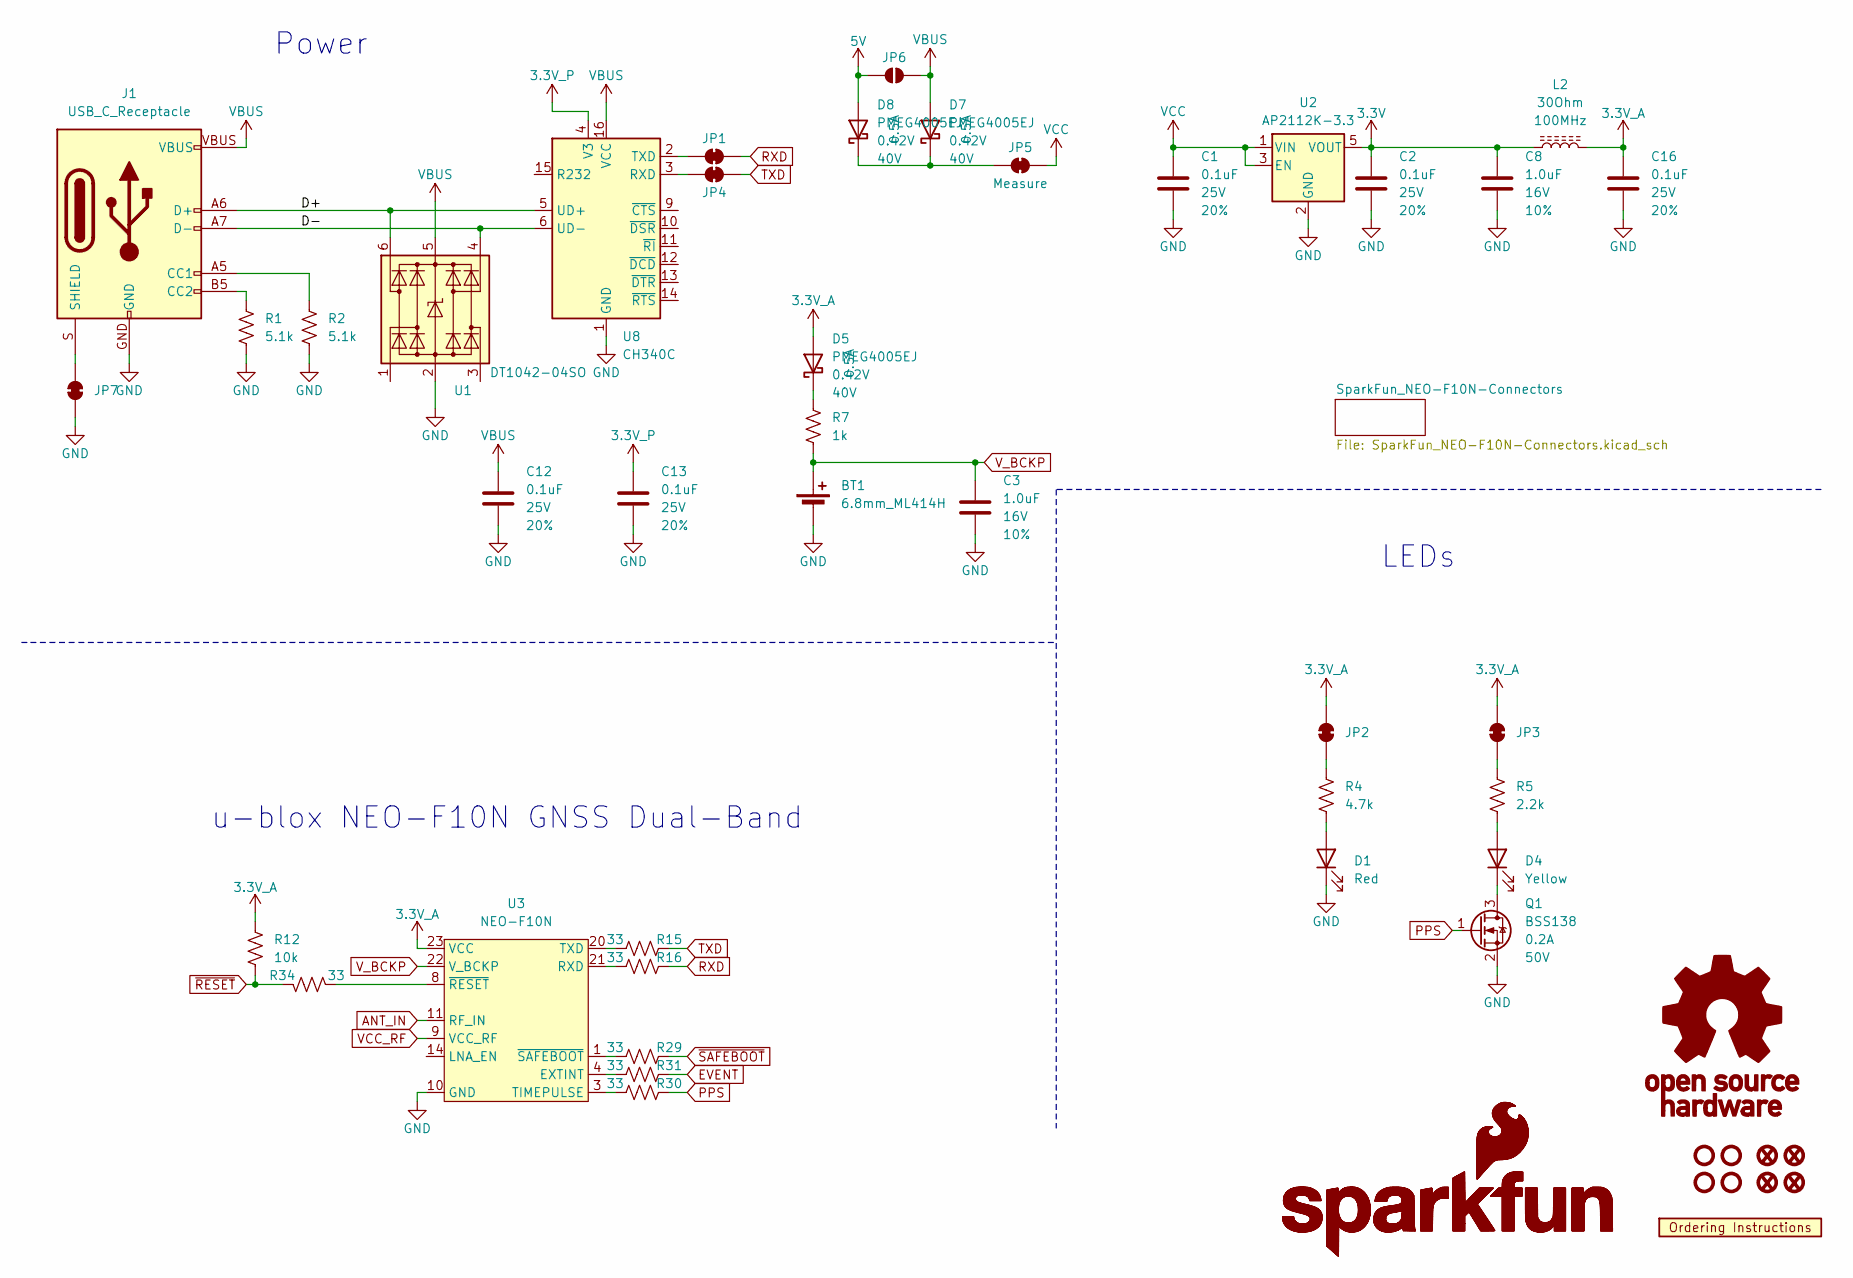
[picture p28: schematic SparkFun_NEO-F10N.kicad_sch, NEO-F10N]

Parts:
BT1: 6.8mm_ML414H; ML414H_IV01E
C1, C2, C12, C13, C16: 0.1uF; C_0603_1608Metric; Voltage 25V; Tolerance 20%
C3, C8: 1.0uF; C_0603_1608Metric; Voltage 16V; Tolerance 10%
D1: Red; LED_0603_1608Metric_Red
D4: Yellow; LED_0603_1608Metric_Yellow
D5, D7, D8: PMEG4005EJ; SOD-323
FID1, FID2, FID3, FID4: Fiducial_0.5mm; Fiducial_0.5mm_Mask1mm
G1: OSHW_Logo; Creative_Commons_License
G3, G5: SparkFun_Logo
J1: USB_C_Receptacle; USB-C_16
JP1, JP2, JP3, JP4, JP7: Jumper_2_NC_Trace
JP5: Measure; Jumper_2_PTH_SMD_Combo-NC
JP6: Jumper_2_NO
L2: 30Ohm; C_0603_1608Metric
Q1: BSS138; SOT23-3
R1, R2: 5.1k; R_0603_1608Metric
R4: 4.7k; R_0603_1608Metric
R5: 2.2k; R_0603_1608Metric
R7: 1k; R_0603_1608Metric
R12: 10k; R_0603_1608Metric
R15, R16, R29, R30, R31, R34: 33; R_0603_1608Metric
ST1, ST2, ST3, ST4: Standoff
U1: DT1042-04SO; SOT23-6
U2: AP2112K-3.3; SOT23-5
U3: NEO-F10N; NEO-M9N_M8T_M8U_D9S_F9P_F10N
U7: Ordering_Instructions
U8: CH340C; SO-16

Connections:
3.3V: C2.1, C8.1, L2.1, U2.5 (VOUT); also elsewhere on the board
3.3V_A: C16.1, D5.A, JP2.2 (B), JP3.2 (B), L2.2, R12.1, U3.23 (VCC)
3.3V_P: C13.1, U8.4 (V3)
5V: D8.A, JP6.1 (A); also elsewhere on the board
/D+: J1.A6 (D+), J1.B6 (D+), U1.6 (I/O4), U8.5 (UD+)
/D-: J1.A7 (D-), J1.B7 (D-), U1.4 (I/O3), U8.6 (UD-)
ANT_IN: U3.11 (RF_IN); also elsewhere on the board
EVENT: R31.2; also elsewhere on the board
GND: BT1.-, C1.2, C2.2, C3.2, C8.2, C12.2, C13.2, C16.2, D1.1 (K), J1.GND, JP7.1 (A), Q1.2 (S), R1.2, R2.2, U1.2 (GND), U2.2 (GND), U3.10 (GND), U3.12 (GND), U3.13 (GND), U3.24 (GND), U8.1 (GND); also elsewhere on the board
unnamed: D1.2 (A), R4.2
unnamed: D4.2 (A), R5.2
unnamed: D4.1 (K), Q1.3 (D)
unnamed: D5.C, R7.1
unnamed: J1.A5 (CC1), R2.1
unnamed: J1.B5 (CC2), R1.1
unnamed: J1.S (SHIELD), JP7.2 (B)
unnamed: JP1.1 (A), U8.2 (TXD)
unnamed: JP2.1 (A), R4.1
unnamed: JP3.1 (A), R5.1
unnamed: JP4.1 (A), U8.3 (RXD)
unnamed: D7.C, D8.C, JP5.1 (A)
unnamed: R31.1, U3.4 (EXTINT)
unnamed: R16.1, U3.21 (RXD)
unnamed: R30.1, U3.3 (TIMEPULSE)
unnamed: R15.1, U3.20 (TXD)
unnamed: R34.2, U3.8 (~RESET)
unnamed: R29.1, U3.1 (~SAFEBOOT)
PPS: Q1.1 (G), R30.2; also elsewhere on the board
RXD: JP1.2 (B), R16.2; also elsewhere on the board
TXD: JP4.2 (B), R15.2; also elsewhere on the board
VBUS: C12.1, D7.A, J1.VBUS, JP6.2 (B), U1.5 (VCC), U8.16 (VCC)
VCC: C1.1, JP5.2 (B), U2.1 (VIN), U2.3 (EN)
VCC_RF: U3.9 (VCC_RF); also elsewhere on the board
V_BCKP: BT1.+, C3.1, R7.2, U3.22 (V_BCKP)
~RESET: R12.2, R34.1; also elsewhere on the board
~SAFEBOOT: R29.2; also elsewhere on the board

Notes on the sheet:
LEDs
u-blox NEO-F10N GNSS Dual-Band
Power

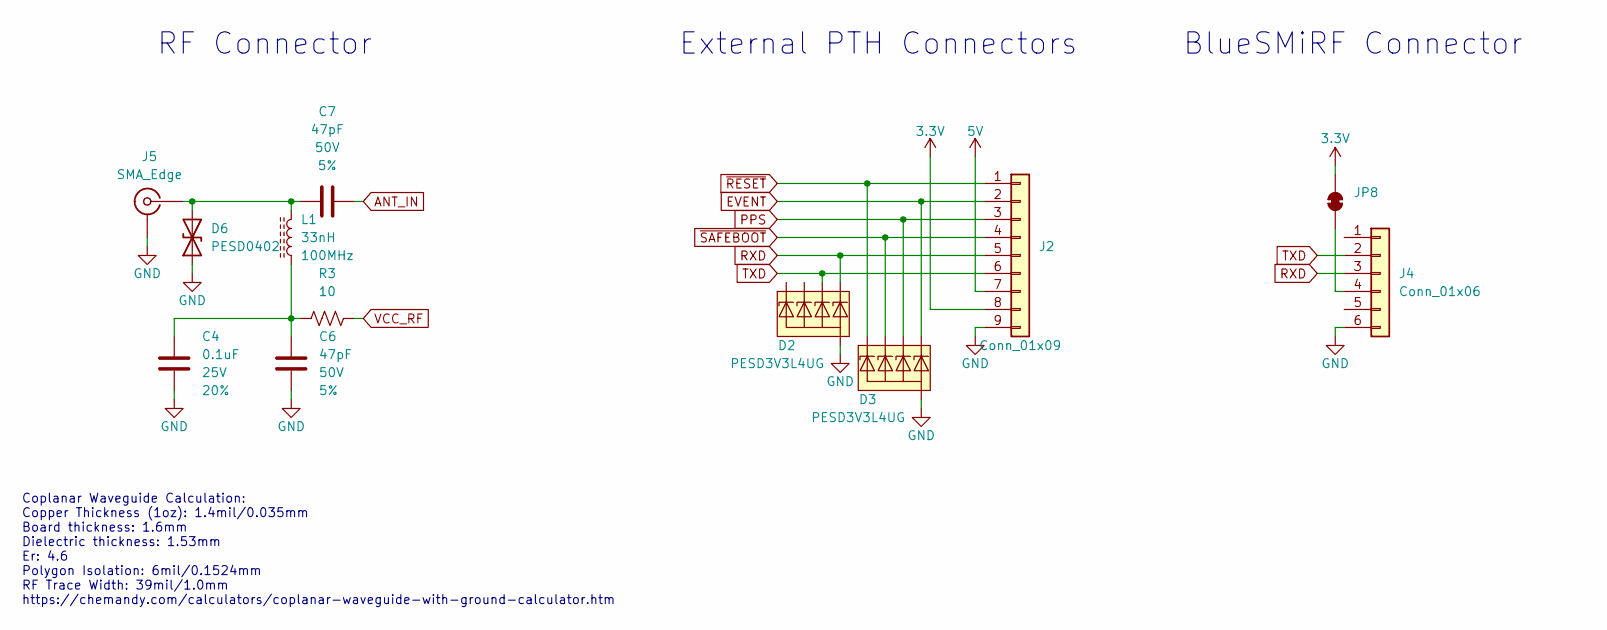
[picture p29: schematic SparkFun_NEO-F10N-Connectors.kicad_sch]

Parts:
C4: 0.1uF; C_0603_1608Metric; Voltage 25V; Tolerance 20%
C6, C7: 47pF; C_0603_1608Metric; Voltage 50V; Tolerance 5%
D2, D3: PESD3V3L4UG; SOT-353
D6: PESD0402; C_0402_1005Metric
J2: Conn_01x09; 1x09
J4: Conn_01x06; 1x06
J5: SMA_Edge
JP8: Jumper_2_NC_Trace
L1: 33nH; C_0603_1608Metric
R3: 10; R_0603_1608Metric

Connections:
3.3V: J2.8, JP8.2 (B); also elsewhere on the board
5V: J2.7; also elsewhere on the board
ANT_IN: C7.2; also elsewhere on the board
EVENT: D3.5 (K4), J2.2; also elsewhere on the board
GND: C4.2, C6.2, D2.2 (A), D3.2 (A), D6.1 (A1), J2.9, J4.6, J5.2 (Ext); also elsewhere on the board
unnamed: C4.1, C6.1, L1.1, R3.1
unnamed: C7.1, D6.2 (A2), J5.1 (In), L1.2
unnamed: J4.4, JP8.1 (A)
PPS: D3.4 (K3), J2.3; also elsewhere on the board
RXD: D2.5 (K4), J2.5, J4.3; also elsewhere on the board
TXD: D2.4 (K3), J2.6, J4.2; also elsewhere on the board
VCC_RF: R3.2; also elsewhere on the board
~RESET: D3.1 (K1), J2.1; also elsewhere on the board
~SAFEBOOT: D3.3 (K2), J2.4; also elsewhere on the board

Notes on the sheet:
External PTH Connectors
Coplanar Waveguide Calculation: Copper Thickness (1oz): 1.4mil/0.035mm Board thickness: 1.6mm Dielectric thickness: 1.53mm Er: 4.6 Polygon Isolation: 6mil/0.1524mm RF Trace Width: 39mil/1.0mm https://chemandy.com/calculators/coplanar-waveguide-with-ground-calculator.htm
RF Connector
BlueSMiRF Connector

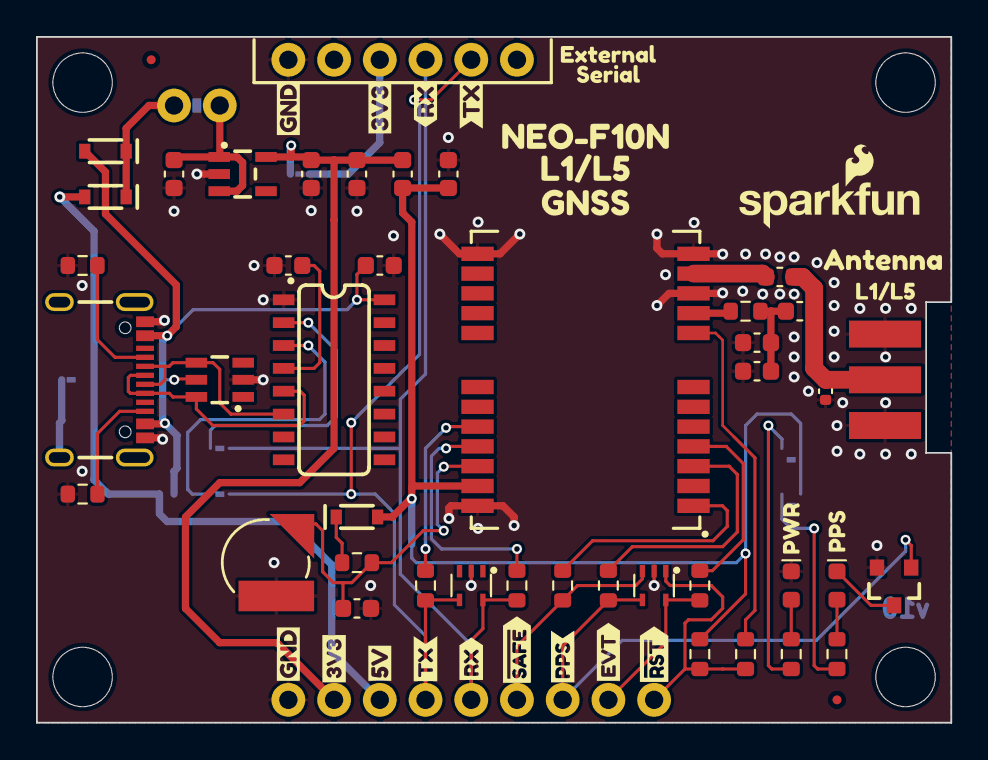
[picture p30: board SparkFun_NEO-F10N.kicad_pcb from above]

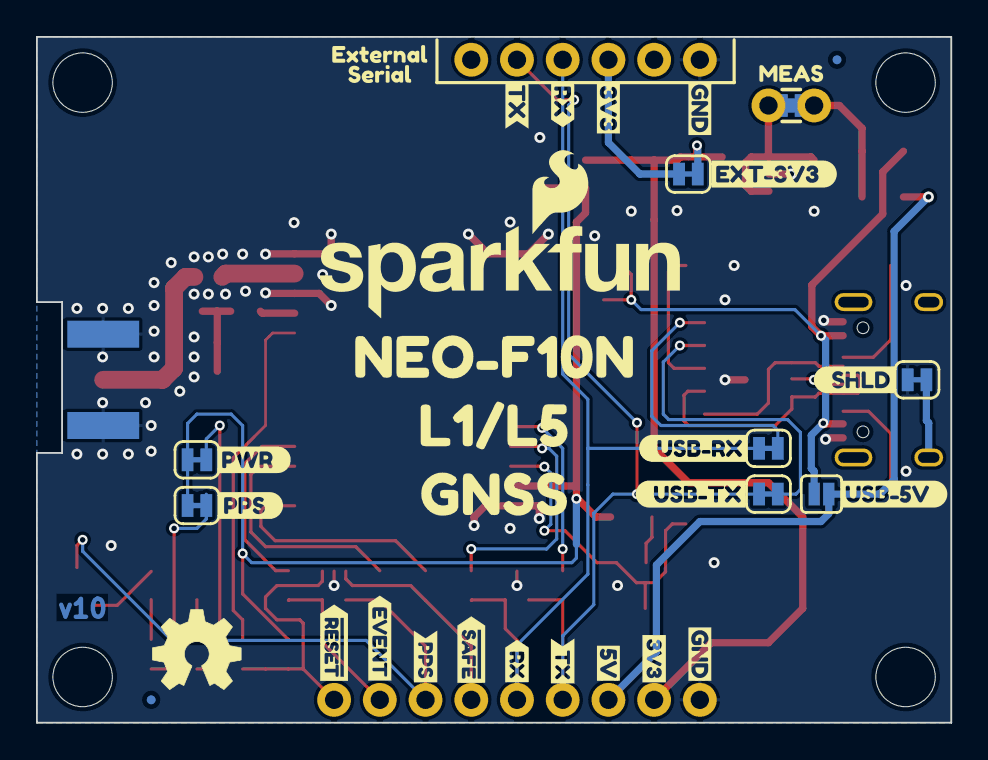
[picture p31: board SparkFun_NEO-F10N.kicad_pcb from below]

Board: 2 copper layers, 50.8 x 38.1 mm, 110 parts (37 on the bottom side), 39 nets.

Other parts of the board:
Ref**: Val**; OSHW_Logo_5mm
kibuzzard-64C2E6A3: G***; kibuzzard-64C2E6A3
kibuzzard-64C2E6BD: G***; kibuzzard-64C2E6BD
kibuzzard-64C2EB16: G***; kibuzzard-64C2EB16
kibuzzard-64D296AE: G***; kibuzzard-64D296AE
kibuzzard-64E773DA, kibuzzard-64E773DA#2: G***; kibuzzard-64E773DA
kibuzzard-64E774E1: G***; kibuzzard-64E774E1
kibuzzard-64E774E7: G***; kibuzzard-64E774E7
kibuzzard-64E774EF: G***; kibuzzard-64E774EF
kibuzzard-64E774F5: G***; kibuzzard-64E774F5
kibuzzard-654D4A62: G***; kibuzzard-654D4A62
kibuzzard-654D4E9F: G***; kibuzzard-654D4E9F
kibuzzard-654D4E65: G***; kibuzzard-654D4E65
kibuzzard-654D4E82: G***; kibuzzard-654D4E82
kibuzzard-654D4EBD: G***; kibuzzard-654D4EBD
kibuzzard-654D22C2, kibuzzard-654D22C2#2: G***; kibuzzard-654D22C2
kibuzzard-654D22ED: G***; kibuzzard-654D22ED
kibuzzard-654D22FF: G***; kibuzzard-654D22FF
kibuzzard-654D24A3: G***; kibuzzard-654D24A3
kibuzzard-654D24AA: G***; kibuzzard-654D24AA
kibuzzard-654D24CA: G***; kibuzzard-654D24CA
kibuzzard-654D232B: G***; kibuzzard-654D232B
kibuzzard-654D2357: G***; kibuzzard-654D2357
kibuzzard-655A6C20: G***; kibuzzard-655A6C20
kibuzzard-655A6C73: G***; kibuzzard-655A6C73
kibuzzard-655A6CC4: G***; kibuzzard-655A6CC4
kibuzzard-655A6CE2: G***; kibuzzard-655A6CE2
kibuzzard-6542D1F0: G***; kibuzzard-6542D1F0
kibuzzard-6542D1FC: G***; kibuzzard-6542D1FC
kibuzzard-6542D20F: G***; kibuzzard-6542D20F
kibuzzard-6542D208: G***; kibuzzard-6542D208
kibuzzard-6598A013: G***; kibuzzard-6598A013
kibuzzard-6598A076: G***; kibuzzard-6598A076
kibuzzard-65989F3D: G***; kibuzzard-65989F3D
kibuzzard-65989F89: G***; kibuzzard-65989F89
kibuzzard-65989F92: G***; kibuzzard-65989F92
kibuzzard-650880E6: G***; kibuzzard-650880E6
kibuzzard-659876FC: G***; kibuzzard-659876FC
kibuzzard-6598770D: G***; kibuzzard-6598770D
kibuzzard-6598978C: G***; kibuzzard-6598978C
kibuzzard-6598994F, kibuzzard-6598994F#2: G***; kibuzzard-6598994F
kibuzzard-65989731, kibuzzard-65989731#2: G***; kibuzzard-65989731
kibuzzard-65989781: G***; kibuzzard-65989781
kibuzzard-65989942, kibuzzard-65989942#2: G***; kibuzzard-65989942

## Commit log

2023-11-13 Remove backup files
    [UM980_antenna.kicad_sch]
2023-11-19 Update datasheet links
    [SparkFun_NEO-F10N-Connectors.kicad_sch, SparkFun_NEO-F10N.kicad_pcb, SparkFun_NEO-F10N.kicad_sch]
2023-11-19 Add bars to RESET and SAFE labels
    [SparkFun_NEO-F10N.kicad_pcb]
2023-11-19 Compress schematic
    [SparkFun_NEO-F10N.kicad_sch]
2024-01-09 Update layout and panel files post design review.
    [SparkFun_NEO-F10N-Connectors.kicad_sch, SparkFun_NEO-F10N.kicad_pcb, SparkFun_NEO-F10N.kicad_sch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]
2024-07-02 Update hardware_hookup.md
    Adjust colors to match wire color since it is hard to see connection from zooming in
2024-08-19 Update 3D models
    [SparkFun_NEO-F10N-Connectors.kicad_sch, SparkFun_NEO-F10N.kicad_pcb, SparkFun_NEO-F10N.kicad_sch]
2024-11-15 Remove STL File
2024-12-10 Update 3D Model with KiCad Library
    USB C and SMA connector were not linked with the latest SparkFun KiCad Library
    [SparkFun_NEO-F10N.kicad_pcb]

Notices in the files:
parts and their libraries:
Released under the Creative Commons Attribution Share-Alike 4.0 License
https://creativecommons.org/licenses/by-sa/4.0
